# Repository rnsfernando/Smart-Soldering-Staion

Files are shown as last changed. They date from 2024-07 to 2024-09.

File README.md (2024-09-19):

# Smart-Soldering-Staion
The SmartSolder Station is a high-performance soldering solution with a soldering iron and hot air gun. 
#### Features:

-Advanced PID Temperature Control  
-Rapid Heating  
-Sleep Mode  
-Tip Change Mode  
-Energy Efficient  
-Reliable Soldering

 Explore our documentation, schematics, and source code to build your own state-of-the-art soldering station.

<table>
  <tr>
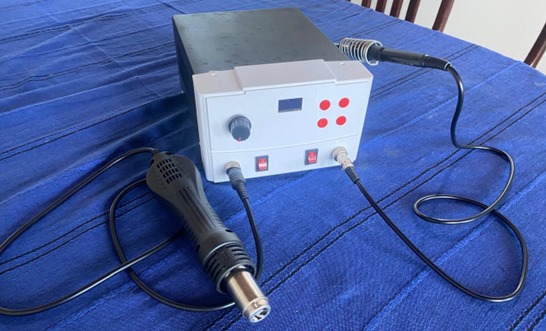
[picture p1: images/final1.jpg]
final1
    <td></td>
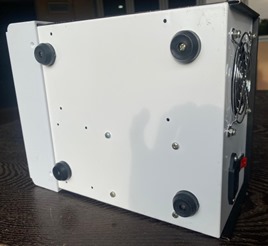
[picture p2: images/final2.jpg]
final2
    <td></td>
  </tr>
  <tr>
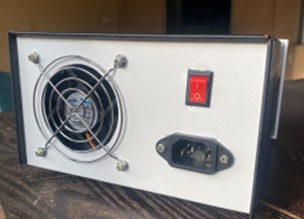
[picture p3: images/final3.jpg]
final3
    <td></td>
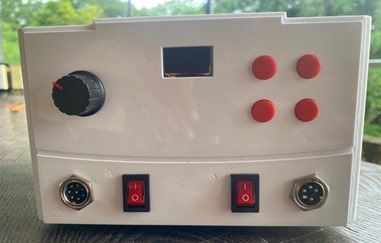
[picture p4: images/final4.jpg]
final4
    <td></td>
  </tr>
</table>

## Table of Contents
- [Introduction](#introduction)
- [Overview](#overview)
- [System Block Diagram](#system-block-diagram)
- [Schematic Diagram](#schematic-diagram)
- [PCB Layout](#pcb-layout)
- [Component List](#component-list)
- [Microcontroller Programming](#microcontroller-programming)
- [Operation](#operation)
- [Safety Features](#safety-features)

## Introduction
The ATmega328P Soldering Station is designed to provide precise temperature control for soldering tasks. This document outlines the design, components, and operation of the soldering station.

## Overview
This soldering station utilizes the ATmega328P microcontroller for temperature control, providing accurate and stable performance. The user interface includes an LCD display and push buttons for setting and monitoring the temperature.

## System Block Diagram
The system block diagram illustrates the main components and their interactions within the soldering station. The microcontroller reads the temperature sensor and controls the heating element to maintain the desired temperature. The user interface allows the user to set the temperature and view the current status.
Block-Diagram

## Schematic Diagram
The schematic diagram provides a detailed view of the electrical connections and components used in the soldering station.

## PCB Layout

### DC PCB
#### Top Layer
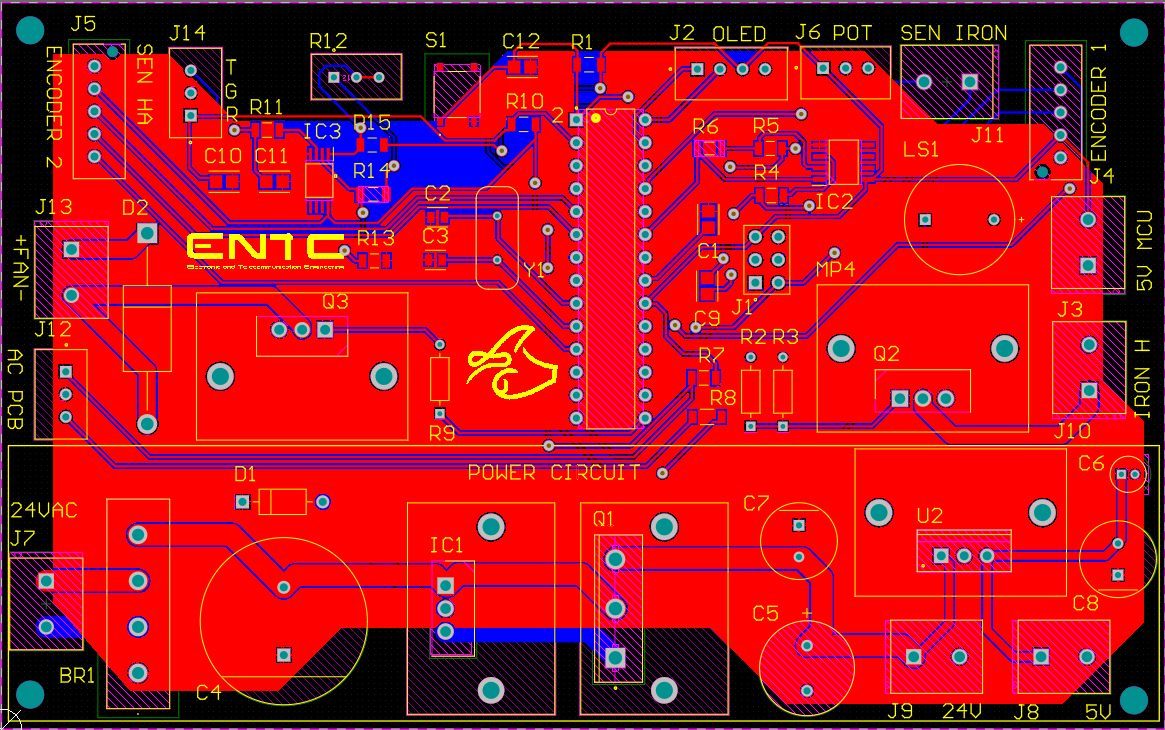
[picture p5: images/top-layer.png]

#### Bottom Layer
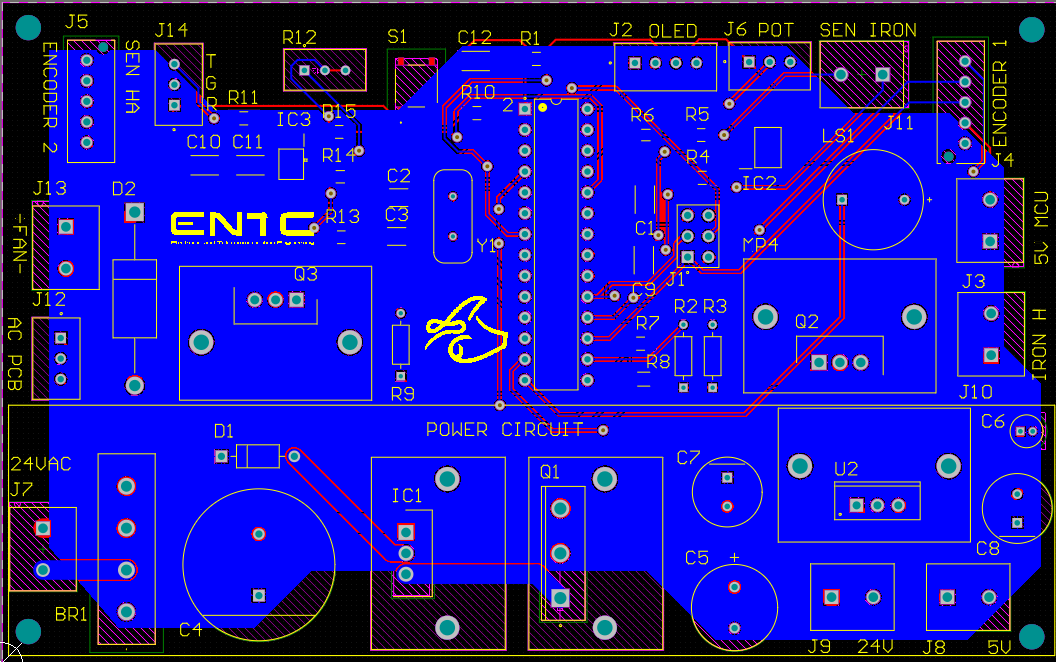
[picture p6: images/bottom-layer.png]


### AC PCB
#### Top Layer
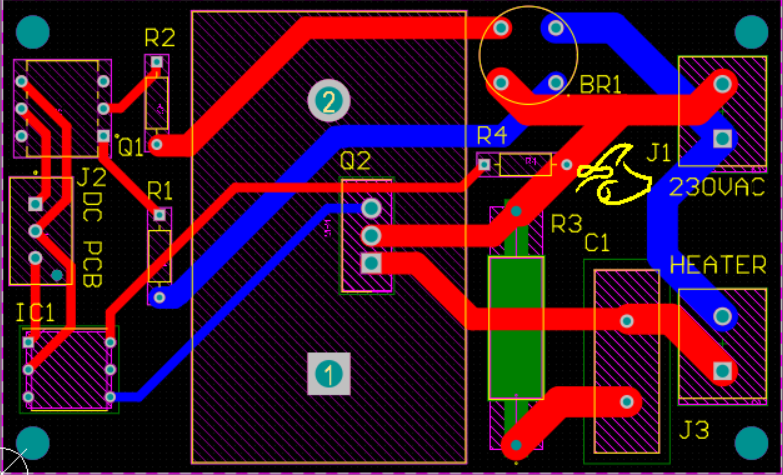
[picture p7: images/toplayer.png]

#### Bottom Layer
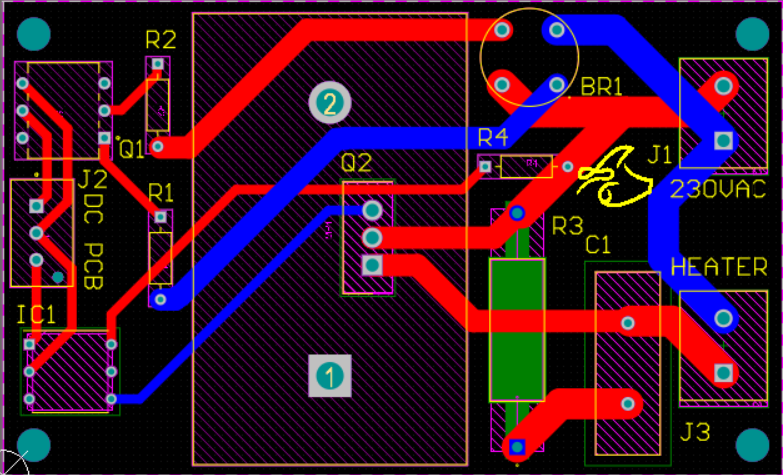
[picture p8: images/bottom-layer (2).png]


### 3D View
### DC PCB
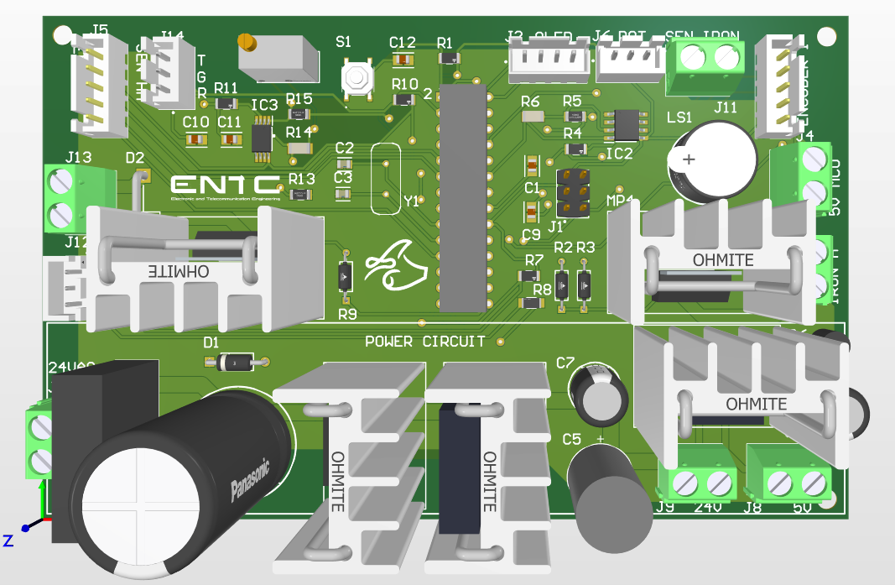
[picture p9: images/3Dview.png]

### AC PCB
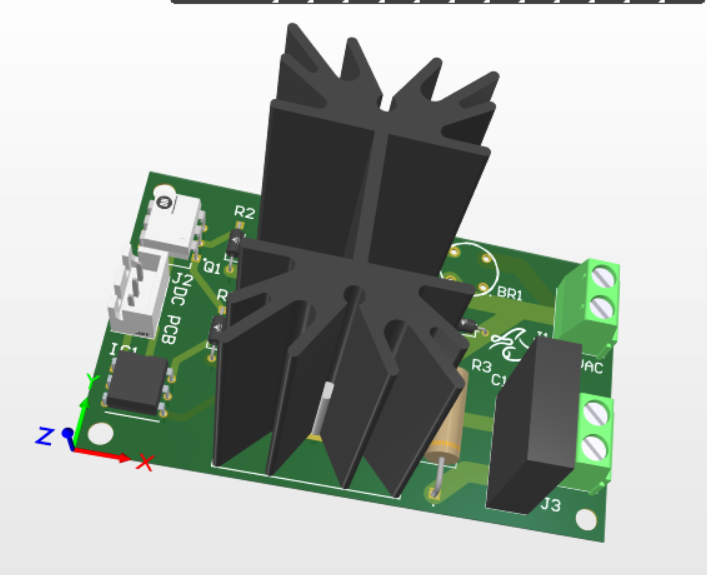
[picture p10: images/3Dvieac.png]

The PCB layout shows the placement of components on the board. The design optimizes space and ensures proper heat dissipation.

## Printed PCB

### DC PCB
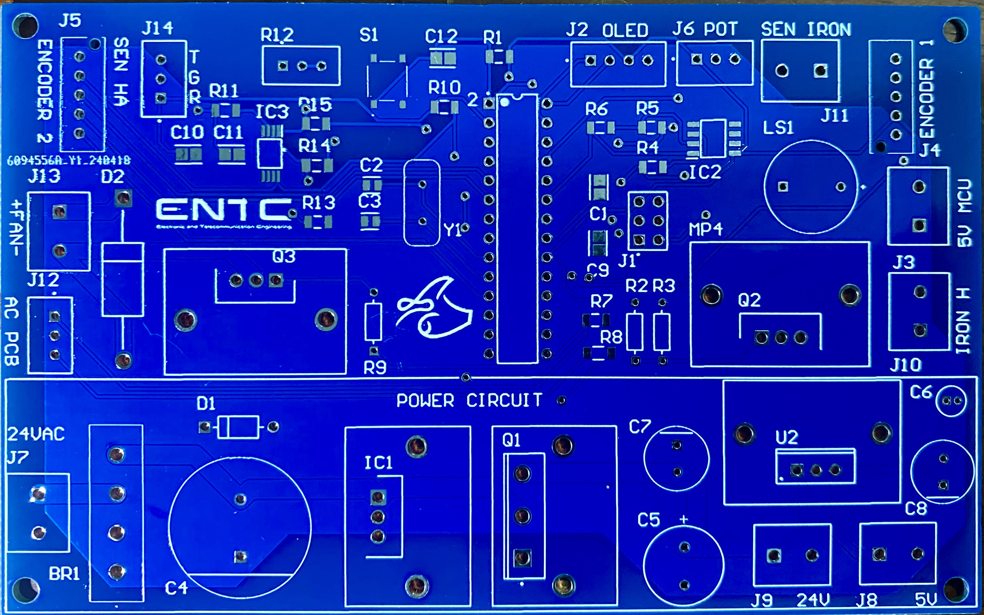
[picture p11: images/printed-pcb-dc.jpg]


### AC-PCB
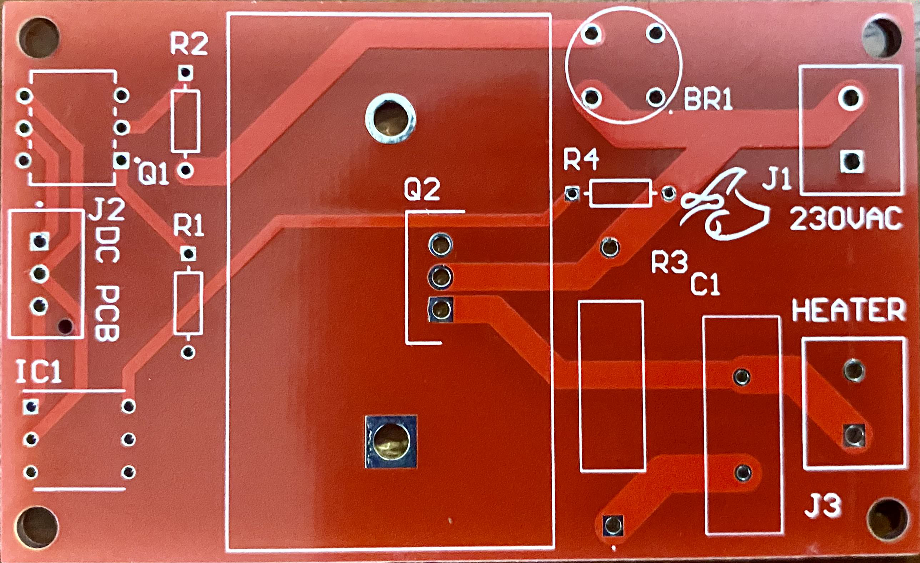
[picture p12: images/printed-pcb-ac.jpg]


## Component List
- **Microcontroller:** ATmega328P
- **Display:** 16x2 LCD screen
- **Temperature Sensor:** Thermocouple
- **Controls:** Push buttons
- **Heating Element:** Soldering iron
- **Other Components:** Resistors, capacitors, connectors

## Wiring Diagram
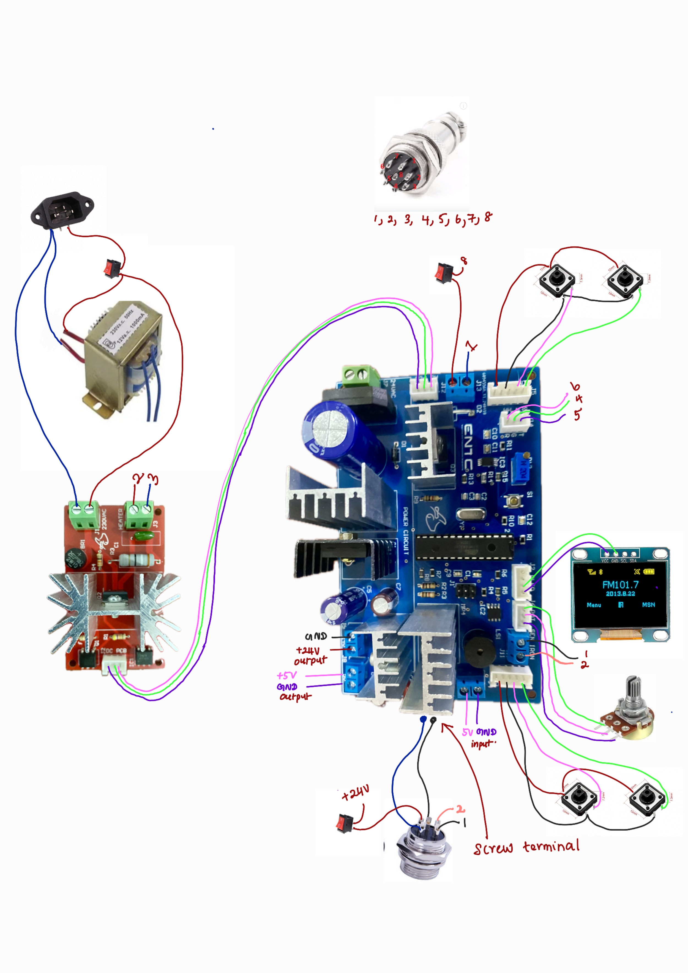
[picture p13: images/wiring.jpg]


## Microcontroller Programming
The ATmega328P microcontroller is programmed using Atmel Studio. Follow these steps to configure and upload the code:

1. **Install Atmel Studio:** Download and install Atmel Studio.
2. **Open Project:** Open the provided project file in Atmel Studio.
3. **Configure Settings:** Set the microcontroller (ATmega328P) and configure fuse bits.
4. **Write Code:** Develop or modify the code as needed.
5. **Build Project:** Compile the project to check for errors.
6. **Upload Code:** Use a programmer (e.g., USBasp) to upload the compiled code to the ATmega328P.

```c
// Example Code Snippet
#include <avr/io.h>
#include <util/delay.h>

#define F_CPU 16000000UL

int main(void) {
    // Set up code
    DDRB |= (1 << PB0); // Set PB0 as output

    while (1) {
        // Main loop
        PORTB ^= (1 << PB0); // Toggle PB0
        _delay_ms(1000); // Delay 1 second
    }
    return 0;
}
The SmartSolder Station is a high-performance soldering solution with a soldering iron and hot air gun. Featuring advanced PID temperature control and multiple modes, it ensures precise, efficient, and reliable soldering. Explore our documentation, schematics, and source code to build your own state-of-the-art soldering station.

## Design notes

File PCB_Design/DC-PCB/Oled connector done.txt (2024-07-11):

Oled connector  done
buzzer
current control done
sensoer input
cooling fan
led(not ness)

**** rotery encoder
pins to code 

24 v fan (24 nvolt ouyput
)
oled ekata 3.3 ekkakuth danna
two switched for iron and hot air gun

power circuit heat sink size care 

power circuit heat sink 

resistor voltage double cheak

5V 5V CONNECT VENATHAN 24 CONNECT VENA CONNECTORS EKA LAGA THYANNA

oni socket tika venama balanna

ho

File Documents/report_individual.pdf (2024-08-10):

## Digital Soldering station

W.W.R.N.S. Fernando – 210169L

## Contribution Report

In this project, I played a significant role in several key areas, ensuring the successful completion of our advanced soldering station. My contributions can be categorized into the following domains:

### 1. SolidWorks Design

I was mainly responsible for the SolidWorks design of the soldering station. This involved:

- 3D Modeling: Creating detailed 3D models of the soldering station components, ensuring precise dimensions and functional design.
- Design Iterations: Collaborating with the team to iterate on the design based on feedback, ensuring the final product met all technical and user requirements.

### 2. Software Development

I also took the lead in the software development aspect of the project, focusing on:

- Temperature Control Algorithm: Developing a robust PID control algorithm to regulate the soldering iron's temperature with high precision.
- Microcontroller Programming: Writing and debugging the code for the microcontroller that manages the soldering station's functions, including temperature control, sleep mode, and tip change mode.
- User Interface: Designing a user-friendly interface that displays real-time temperature readings and allows users to adjust settings easily.

### 3. Design Methodology

Throughout the project, I actively contributed to the overall design methodology, including:

- Concept Development: Participating in brainstorming sessions to develop innovative concepts and features for the soldering station.
- Decision Making: Assisting in the decision-making process by evaluating different design options and selecting the most feasible solutions.
- Prototyping: Helping to build and test prototypes to validate design concepts and refine the final product.

### 4. Circuit Design Finalization

In addition to my primary focus areas, I contributed to finalizing the circuit designs by:
- Circuit Design Review: Reviewing circuit schematics to ensure they met the project's requirements and industry standards.
- Component Selection: Assisting in selecting appropriate components that provided reliable performance and compatibility with the overall design.
- Testing and Validation: Helping to test and validate the circuits to ensure they functioned correctly and integrated well with the rest of the system.

### 5. Documentation Assistance

Lastly, I supported the documentation process by:

- Design Documentation: Assisting in creating detailed technical documents that described the solid works design, and software part of the soldering station.
- Design methodology: Contributed to developing the design methodology report based on the Cambridge model.

### 6. PCB design

I contributed to finalizing the PCB design by:

- PCB Layout: Assisting in the design of the PCB layout to ensure optimal component placement, signal integrity, and manufacturability.
- Design Review: Reviewing the PCB design to ensure it met all project requirements and industry standards.
- Component Selection: Helping to choose suitable components that provided reliable performance and compatibility with the overall design.
- Testing and Validation: Participating in the testing and validation process to ensure the PCB functioned correctly and integrated seamlessly with the rest of the system.

### 7. PCB Soldering and Testing

I contributed to soldering and testing the PCB:

- PCB Soldering: Assisted in soldering the PCBs to ensure all components were properly attached.
- MCU Circuit Testing: Participated in testing the Microcontroller Unit (MCU) circuit to verify its functionality.
- Power Supply Circuit Testing: Conducted tests on the power supply circuit to ensure it operated correctly.
- Functionality Confirmation: Verified that both circuits worked as intended and that the soldering was done accurately.

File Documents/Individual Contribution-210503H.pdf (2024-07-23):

# Department of Electronics and Telecommunications

## University of Moratuwa

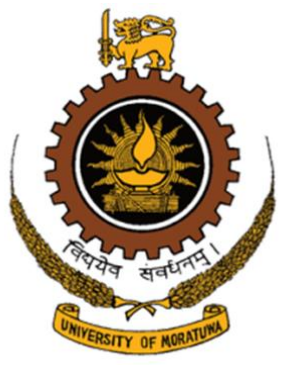
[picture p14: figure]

# Individual Contribution Report: Soldering Station Project

EN2160

## Engineering Design Realization

## 210503H- I.P.D.D. Rajapaksha

This report highlights my individual contributions to the soldering station project. My involvement spanned various phases, including research, design, simulation, prototyping, component selection, schematic and PCB design, code finalization, and testing. The following sections detail each contribution.

Research and Circuit Design

I conducted extensive research in two main categories: product analysis and circuit design. First, I focused on industrial products and market-available products, examining their features and specifications to understand the current standards and innovations. This research provided valuable insights into what makes a successful soldering station. Secondly, I delved into circuit design, specifically for both AC and DC circuits. I explored various sub-circuits, learning about their functions and how to integrate them effectively. This foundational work on product features and circuit design was crucial in ensuring the project's success and informed the overall development of both the AC and DC PCB circuits.

Circuit Design

I was responsible for designing the circuits for two separate PCBs: the AC PCB and the DC PCB. This involved creating detailed schematics and layout designs, including essential circuits such as the current-controlling power supply, MCU, temperature sensing and amplifying, and the AC PCB with TRIAC trigger configuration. I used industry-standard design software to optimize these designs for performance and reliability. These designs were crucial for the efficient and reliable operation of the soldering station.

Schematic and PCB Design for AC and DC Circuits

I created detailed schematics and PCB layouts for both the AC and DC circuits. This work required precision and attention to detail to ensure that the circuits would function correctly and safely. The designs were thoroughly reviewed and optimized for manufacturing.

Simulation and Prototyping

To validate the circuit designs, I performed simulations using Multisim. These simulations helped identify potential issues and allowed for iterative improvements. Following successful simulations, I constructed a prototype using a dotboard to test the power supply circuit. This hands-on testing confirmed the circuit's functionality and performance under real-world conditions, ensuring its stability and reliability.

Component Selection

Another significant contribution was selecting the appropriate components for the project. This task required careful consideration of various factors such as compatibility, reliability, and cost. I performed the relevant calculations to ensure optimal performance and selected high-quality components that would guarantee the soldering station's reliable and efficient operation.

Enclosure Design

I assisted in finalizing the design of the enclosure for the soldering station. This involved collaborating with the team to ensure the enclosure was both functional and aesthetically pleasing. The enclosure design needed to accommodate all components securely while allowing for adequate ventilation and ease of use.

Software Development

Another significant contribution was the software development for the project. I conducted thorough research to identify relevant techniques and features needed for the soldering station. Based on this research, I finalized the structure of the algorithm, ensuring it incorporated essential features such as PID control, pin change mode, sleep mode, and others. I played a crucial role in finalizing the main code, debugging, and refining it to ensure seamless integration with the hardware. This structured approach to coding was essential for the efficient and reliable operation of the soldering station, managing temperature control and other functionalities effectively.

Soldering and Testing

I participated in soldering the PCBs and testing the MCU (Microcontroller Unit) circuit and power supply circuit. These tests confirmed that the circuits worked as intended and that the soldering was done correctly. The successful testing phase was a critical step in moving the project toward completion.

Documentation Assistance

Technical Documentation: Assisting in the creation of comprehensive technical documents that detailed the circuit design, including schematics and PCB layout for various parts of the soldering station.

Design Methodology: Contributing to the development of the design methodology report, which was based on the Cambridge model, ensuring a structured and methodical approach to the design process.

This comprehensive research encompassed product analysis and circuit design, providing essential insights into industry standards and innovative practices. It was instrumental in shaping the development of both AC and DC PCB circuits for the soldering station, ensuring their effective integration and optimal performance.

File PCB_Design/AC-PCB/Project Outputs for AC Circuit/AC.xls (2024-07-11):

Board Stack Report
Stack Up |  | Layer Stack
Layer | Board Layer Stack | Name | Material | Thickness | Constant
1 |  | Top Overlay |  | 0mil
2 |  | Top Solder | Solder Resist | 0.4mil | 3.5
3 |  | Top Layer |  | 1.4mil
4 |  | Dielectric 1 | FR-4 | 12.6mil | 4.8
5 |  | Bottom Layer |  | 1.4mil
6 |  | Bottom Solder | Solder Resist | 0.4mil | 3.5
7 |  | Bottom Overlay |  | 0mil
 | Height : 16.2mil

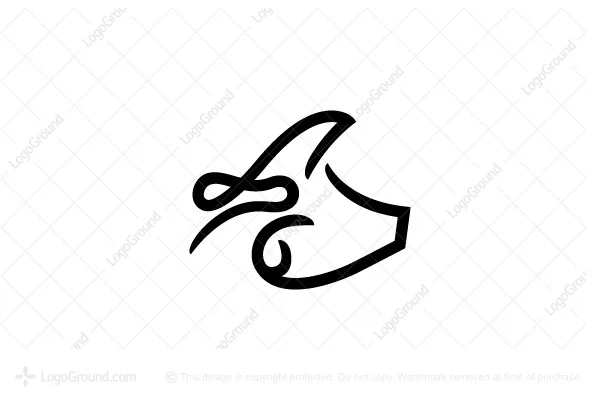
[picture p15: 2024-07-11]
PCB_Design/DC-PCB/dv12y202344582023-11-183462807chicken and pig head farm-01.png

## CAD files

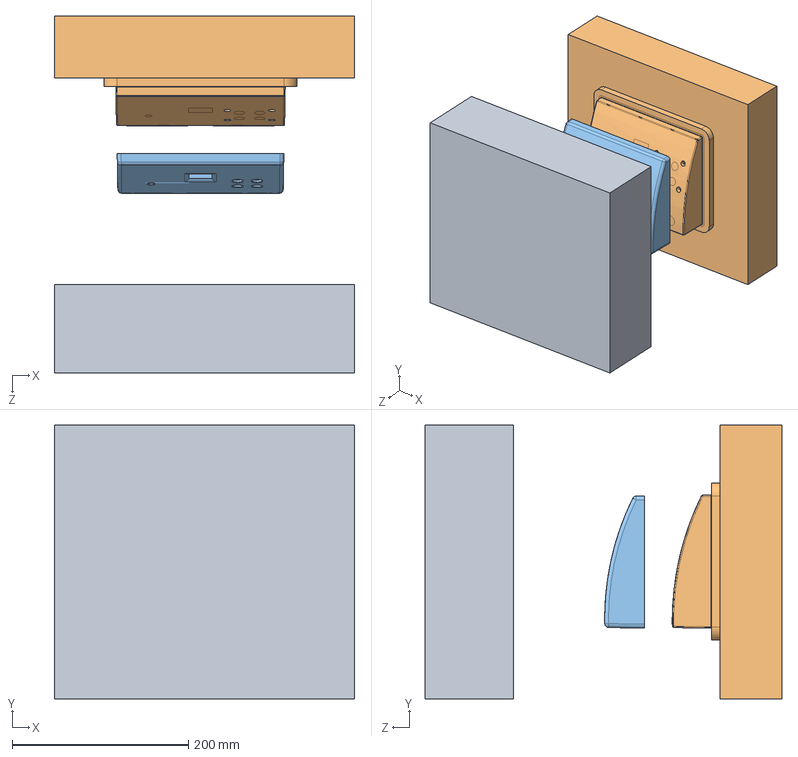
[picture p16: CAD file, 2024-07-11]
Enclosure-Design/Mold-Design/1.0-Design/Assem1.SLDASM
340.0 x 310.0 x 404.4 mm
face-cavity
face-core
new_face

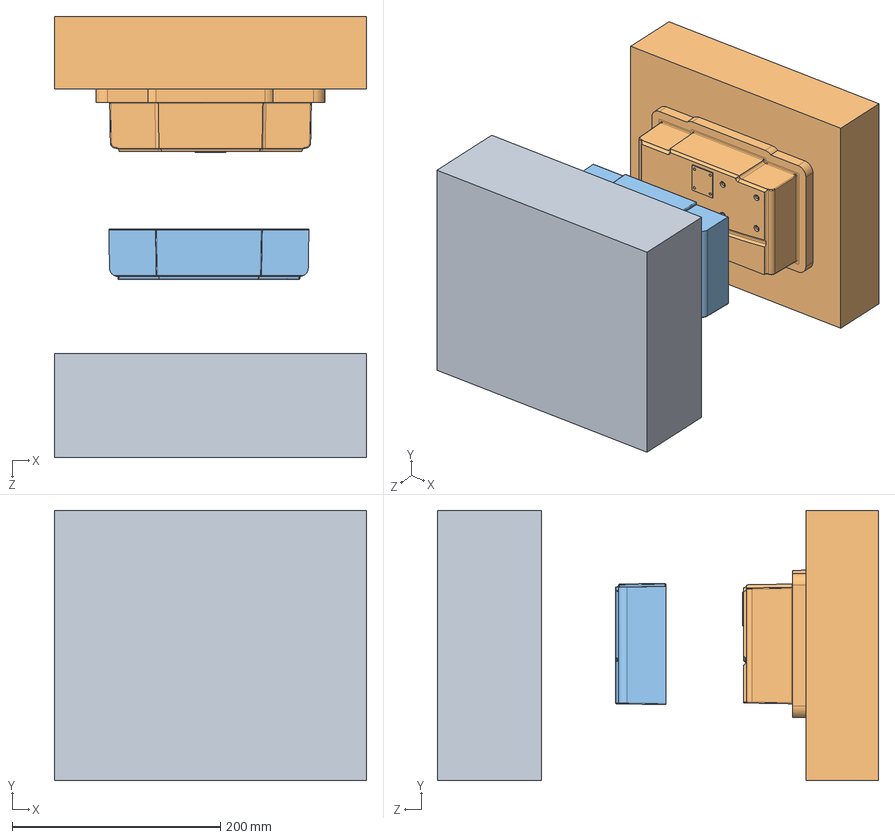
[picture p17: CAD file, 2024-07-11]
Enclosure-Design/Mold-Design/2.0-Design/Assem2.SLDASM
300.0 x 260.0 x 424.3 mm
metal final face_moldable-Cavity
metal final face_moldable-Core
final face_moldable

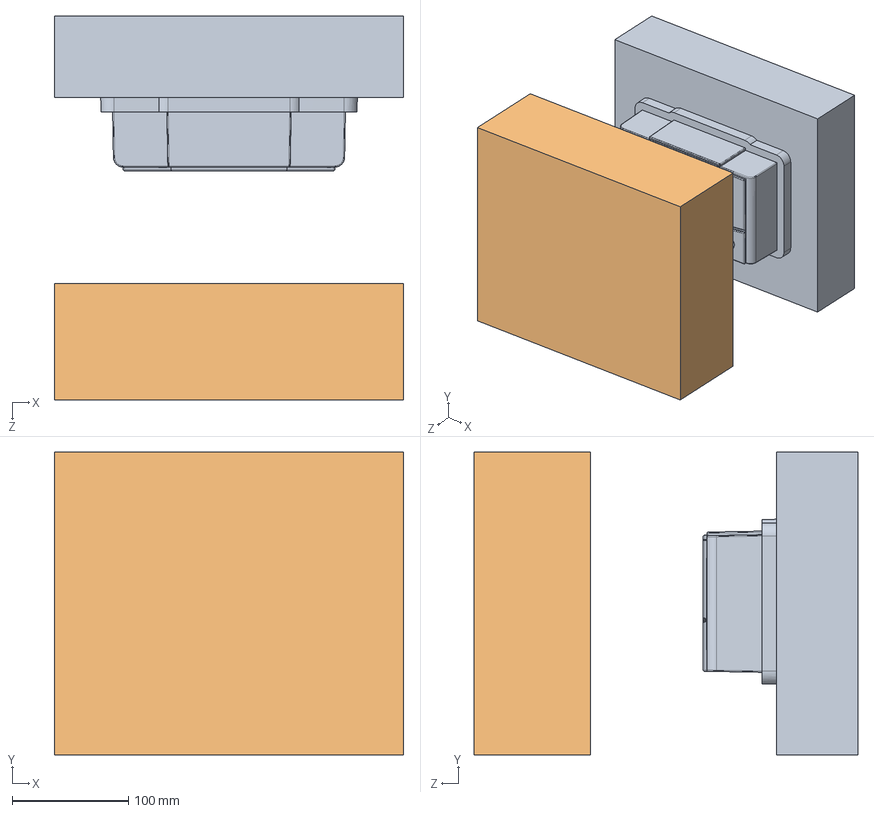
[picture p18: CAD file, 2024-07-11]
Enclosure-Design/Mold-Design/2.0-Design/Assem1.SLDASM
300.0 x 260.0 x 330.0 mm
metal final face_moldable
metal final face_moldable-Cavity

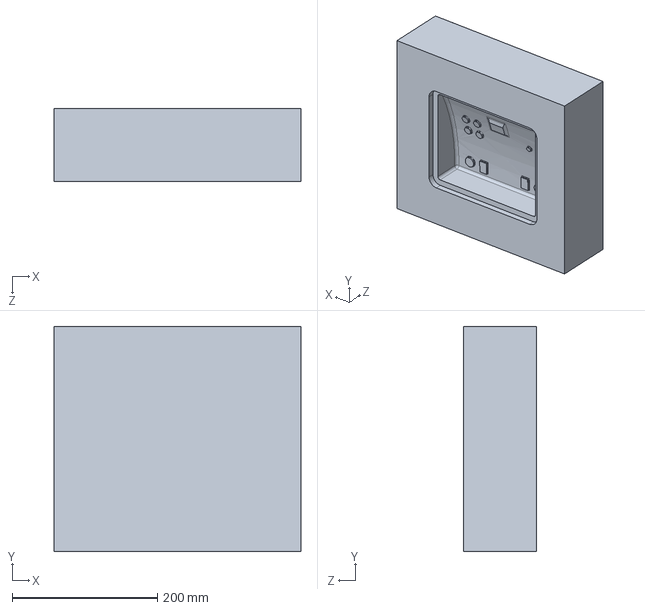
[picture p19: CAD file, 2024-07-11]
Enclosure-Design/Mold-Design/1.0-Design/face-cavity.SLDPRT
340.0 x 310.0 x 100.0 mm

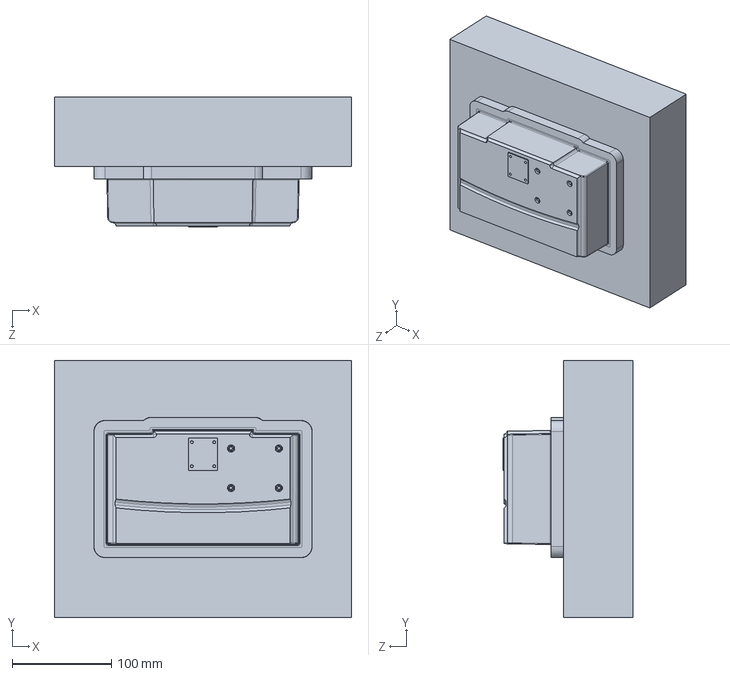
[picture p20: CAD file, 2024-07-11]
Enclosure-Design/Mold-Design/2.0-Design/metal final face_moldable-Core.SLDPRT
300.0 x 260.0 x 131.1 mm

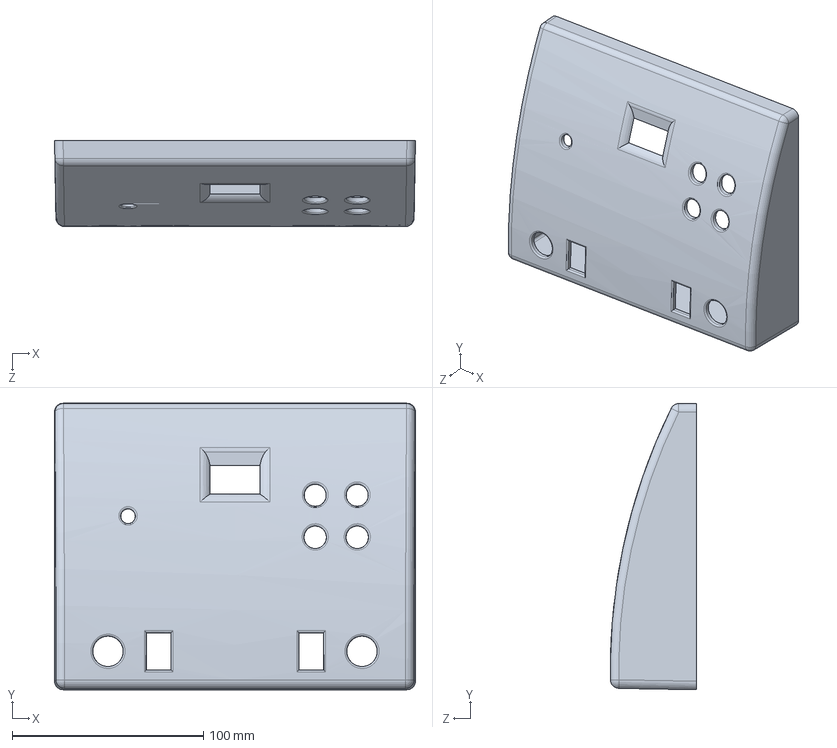
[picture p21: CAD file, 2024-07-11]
Enclosure-Design/Mold-Design/1.0-Design/Design1.SLDPRT
189.0 x 150.0 x 45.2 mm

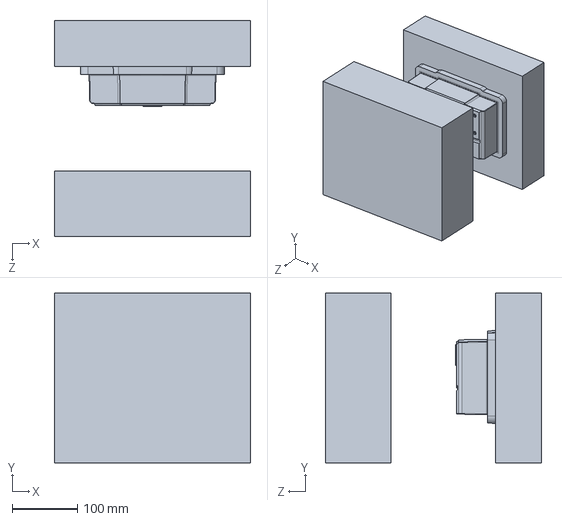
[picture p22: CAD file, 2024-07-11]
Enclosure-Design/Mold-Design/2.0-Design/metal final face_moldableboth.SLDPRT
300.0 x 260.0 x 330.0 mm

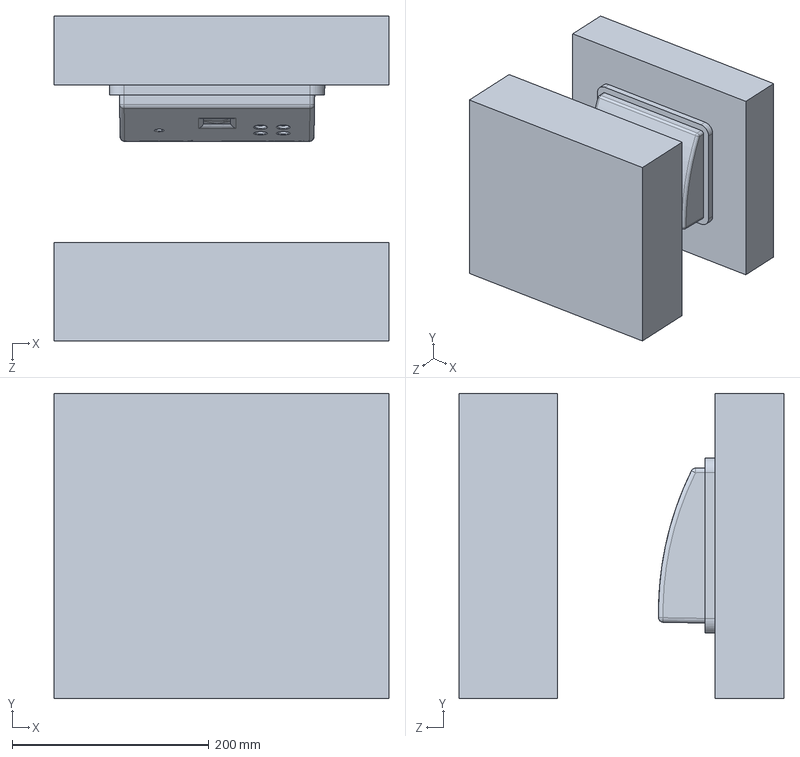
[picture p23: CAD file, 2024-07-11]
Enclosure-Design/Mold-Design/1.0-Design/face.SLDPRT
340.0 x 310.0 x 330.0 mm

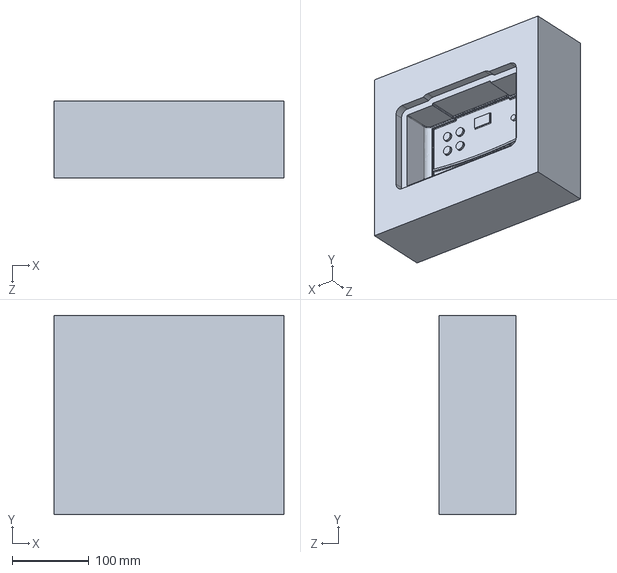
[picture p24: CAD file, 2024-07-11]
Enclosure-Design/Mold-Design/2.0-Design/metal final face_moldable-Cavity.SLDPRT
300.0 x 260.0 x 100.0 mm

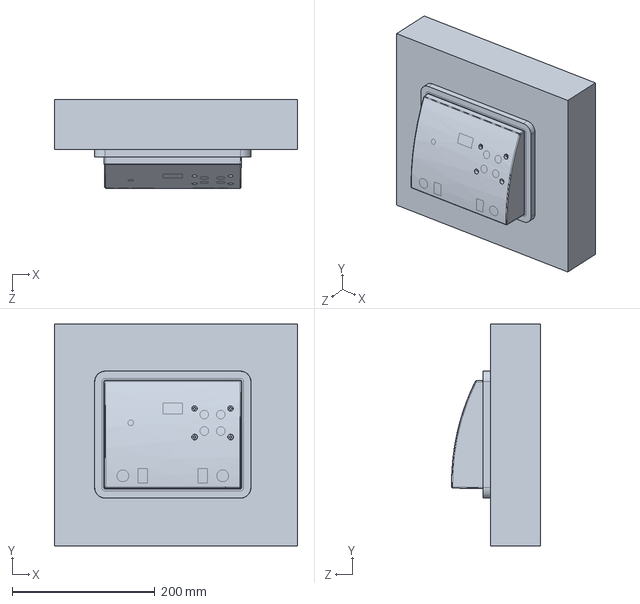
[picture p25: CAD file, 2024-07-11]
Enclosure-Design/Mold-Design/1.0-Design/face-core.SLDPRT
340.0 x 310.0 x 124.3 mm

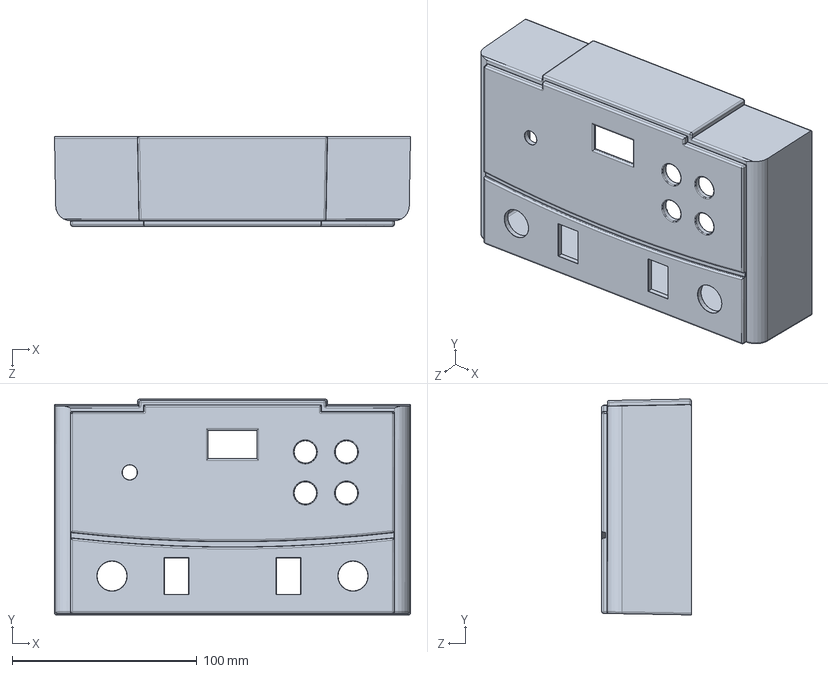
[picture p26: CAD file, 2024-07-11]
Enclosure-Design/Mold-Design/2.0-Design/final face_moldable.SLDPRT
192.5 x 116.7 x 48.5 mm

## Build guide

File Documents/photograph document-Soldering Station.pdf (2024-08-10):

# Department of Electronics and Telecommunications

# University of Moratuwa

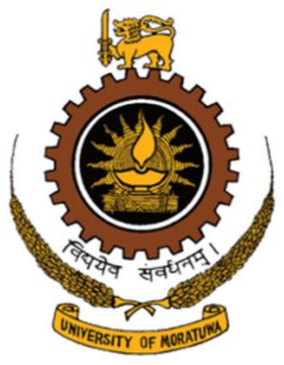
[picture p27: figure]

# Photographs Documentation

# Soldering Station

EN2160

## Engineering Design Realization

210169L- W.W.R.N.S. Fernando

210503H- I.P.D.D. Rajapaksha

## Contents

## 1.0. Photographs of the bare PCB

### 1.1. DC PCB

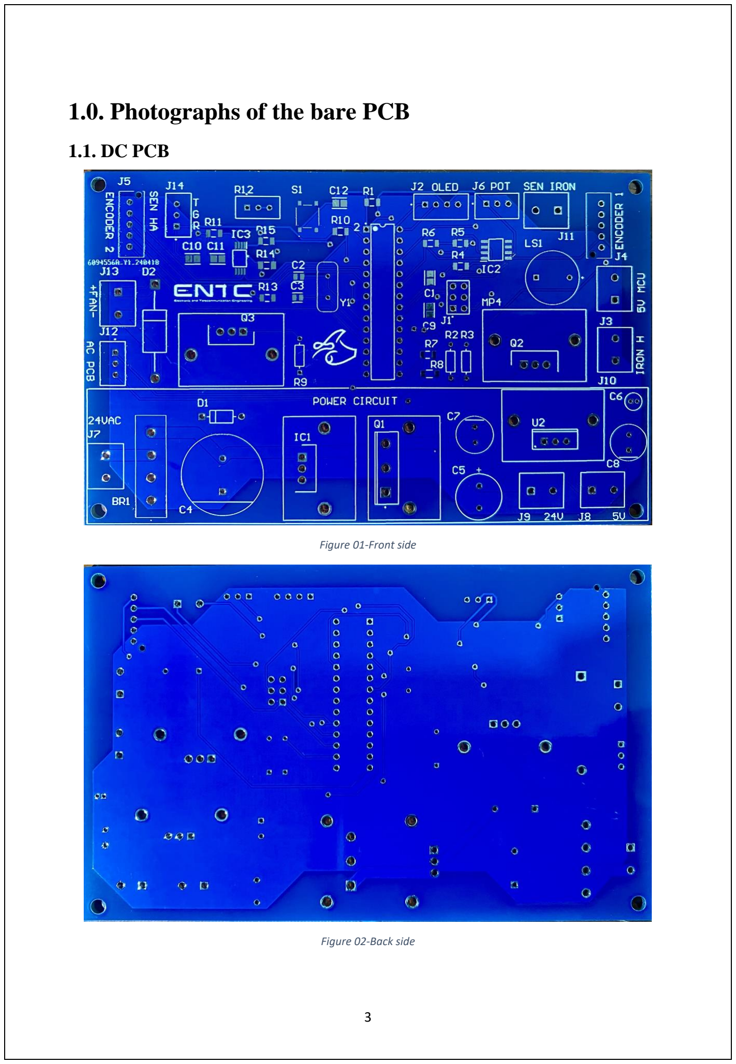
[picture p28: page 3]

Figure 01-Front side

Figure 02-Back side

### 1.2. AC PCB

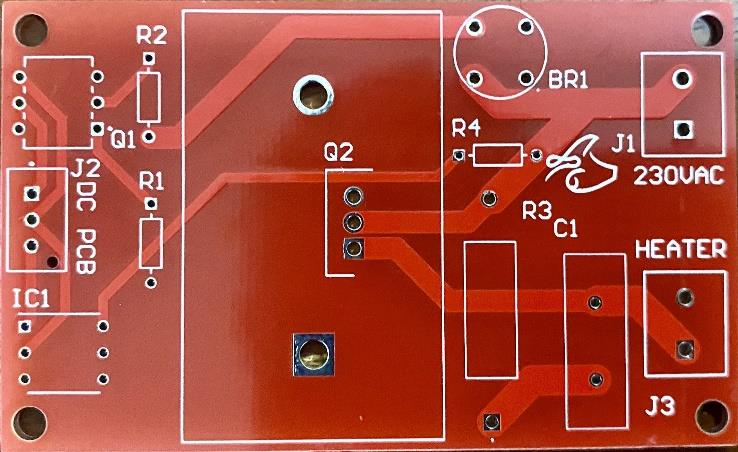
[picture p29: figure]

Figure 03-Front side

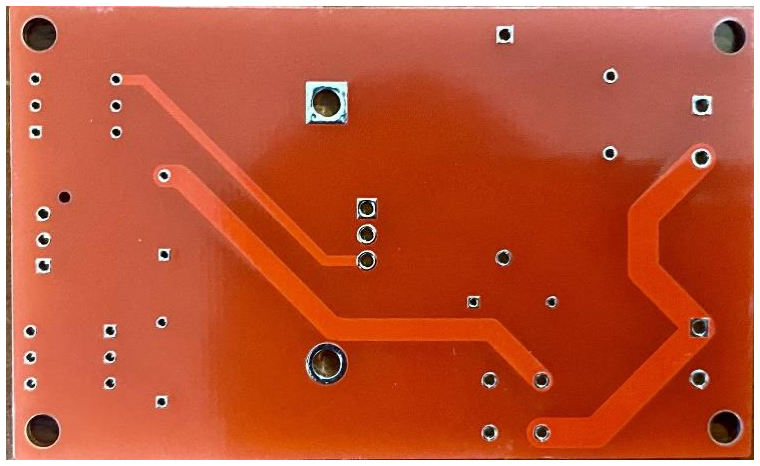
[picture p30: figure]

Figure 04-Back side

## 2.0. Photograph

### 2.1. DC PCB

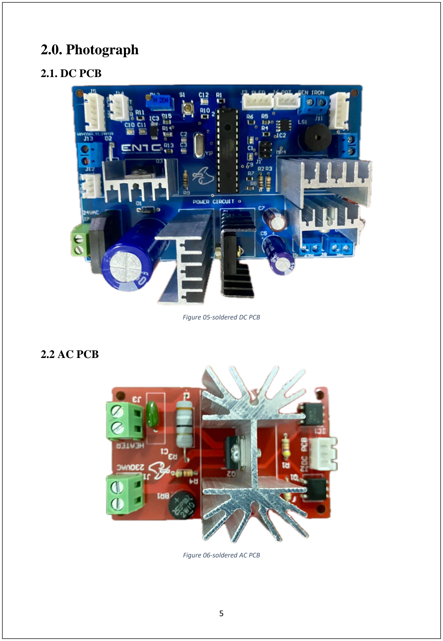
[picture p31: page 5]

Figure 05-soldered DC PCB

### 2.2 AC PCB

Figure 06-soldered AC PCB

## 3.0. Photographs as evidence for the PCB testing

The power supply circuit, microcontroller circuit, current controlling circuit, and amplifier circuit were tested before the labs closed due to a non-academic staff strike. The AC PCB, hot air current control, and amplifier still need to be tested, and the PID code for the soldering iron needs tuning. These tasks require a signal generator, an oscilloscope, and a power supply.

### 3.1. Sensor (Amplifier) testing

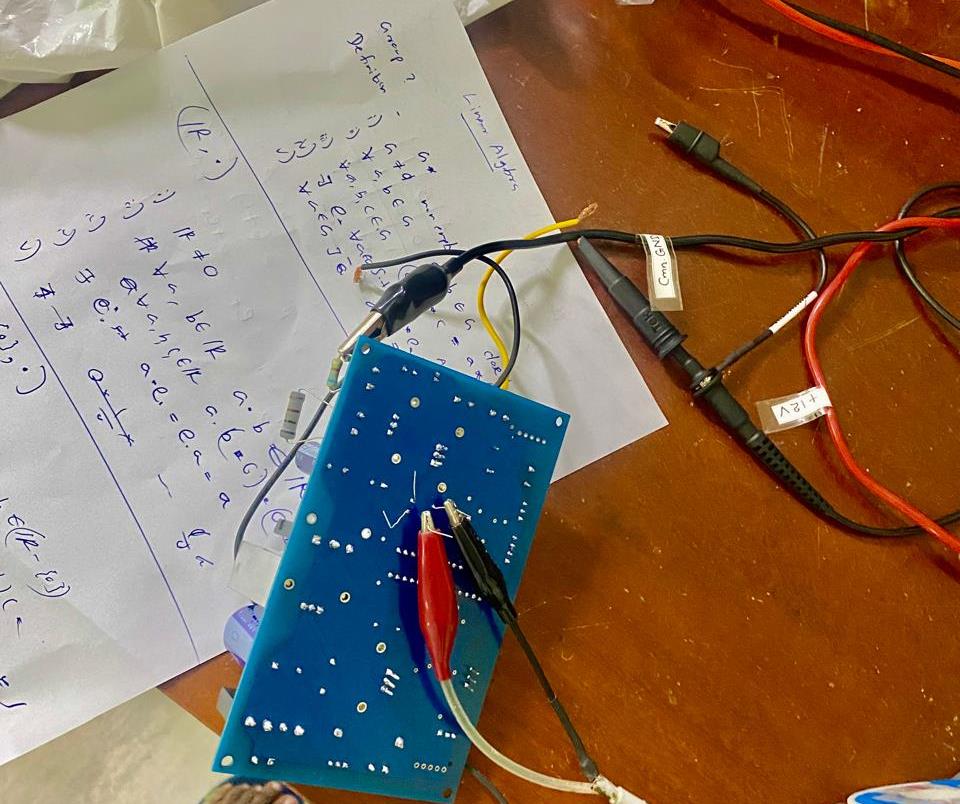
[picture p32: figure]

Figure 07 - Testing

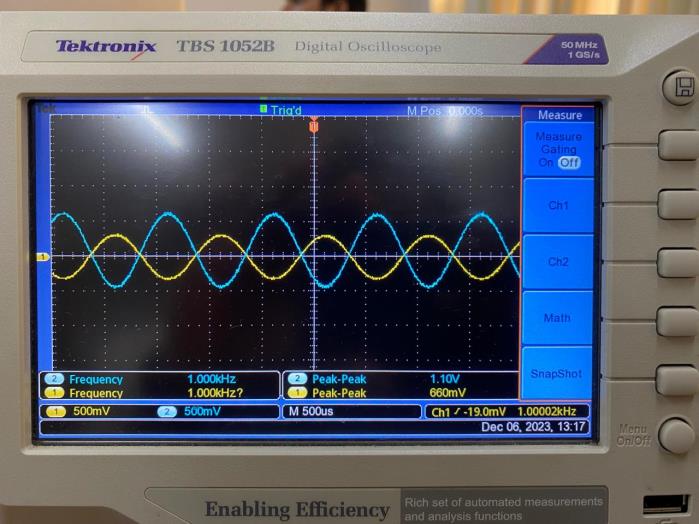
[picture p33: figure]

Figure 08 - Sensor output

## 4.0. Photographs of the physically built enclosure/functional (mechanical) parts

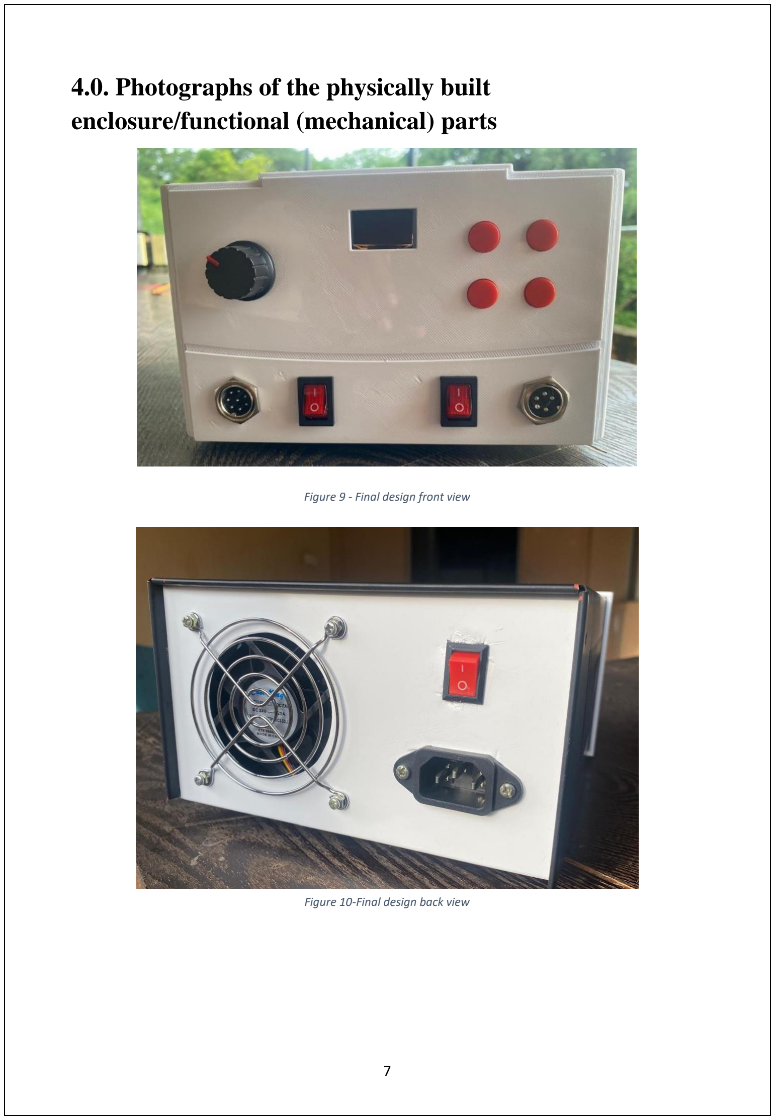
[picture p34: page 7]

Figure 9 - Final design front view

Figure 10-Final design back view

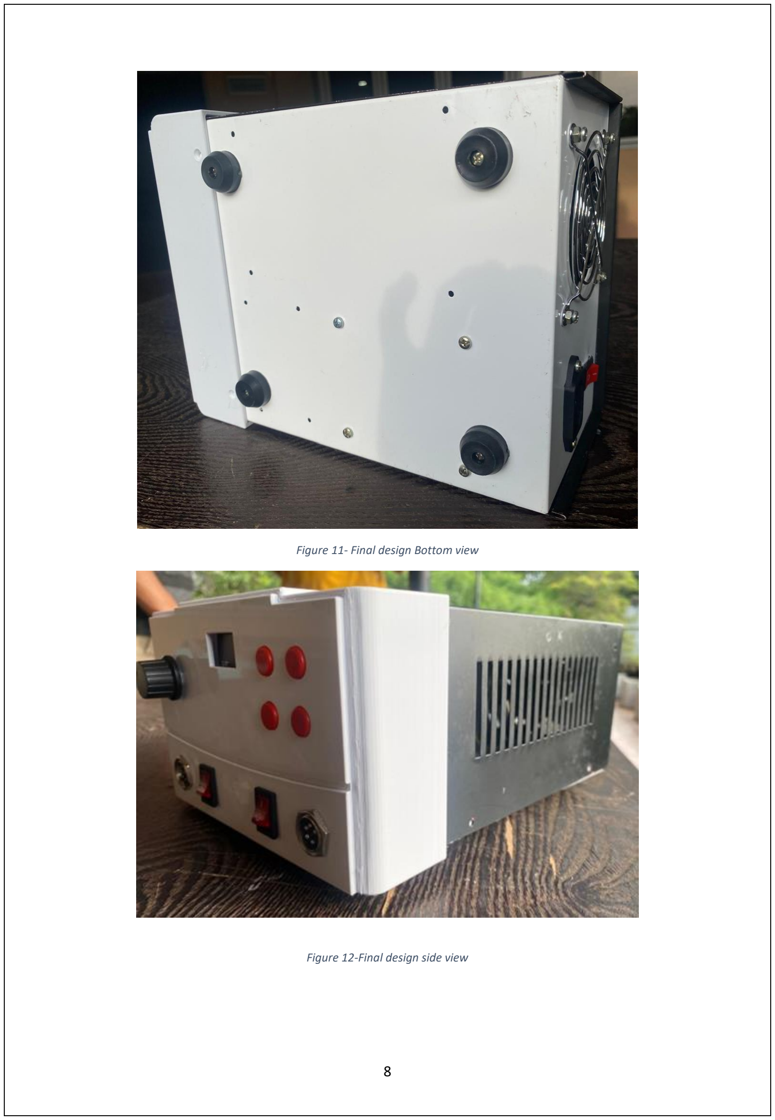
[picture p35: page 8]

Figure 11- Final design Bottom view

Figure 12-Final design side view

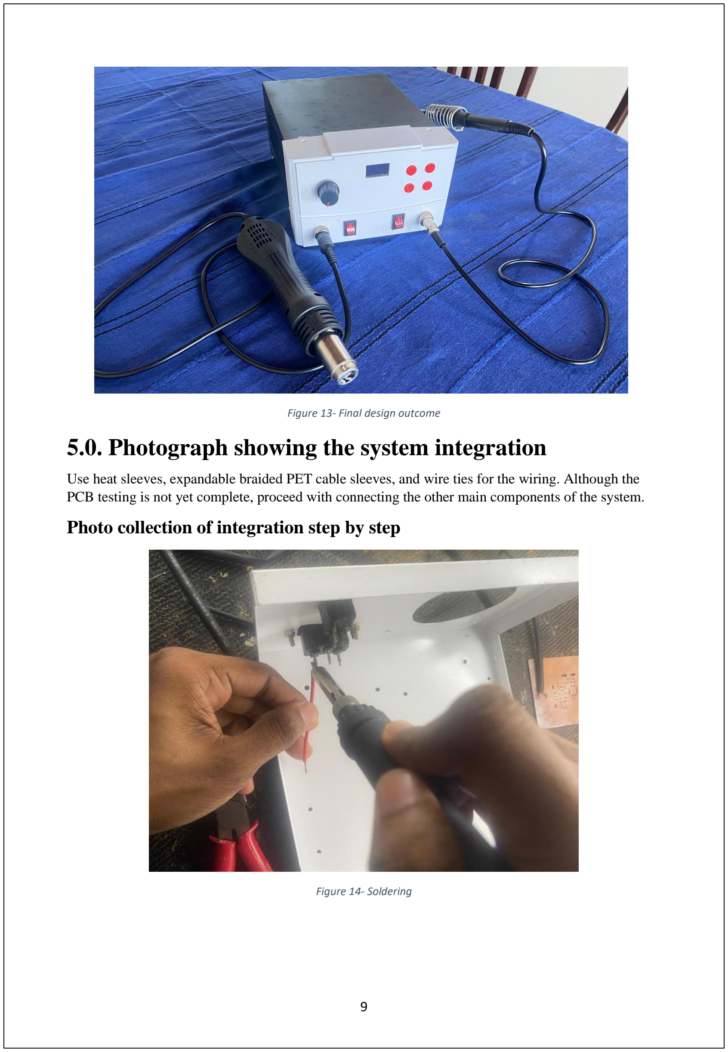
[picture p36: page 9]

Figure 13- Final design outcome

## 5.0. Photograph showing the system integration

Use heat sleeves, expandable braided PET cable sleeves, and wire ties for the wiring. Although the PCB testing is not yet complete, proceed with connecting the other main components of the system.

### Photo collection of integration step by step

Figure 14- Soldering

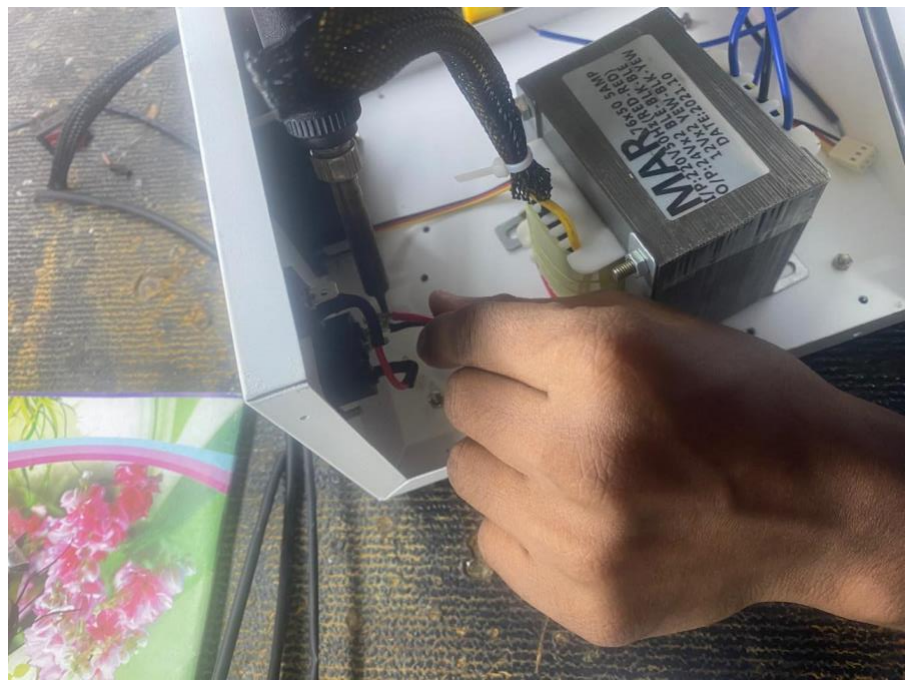
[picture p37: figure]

Figure 15-connecting transformer

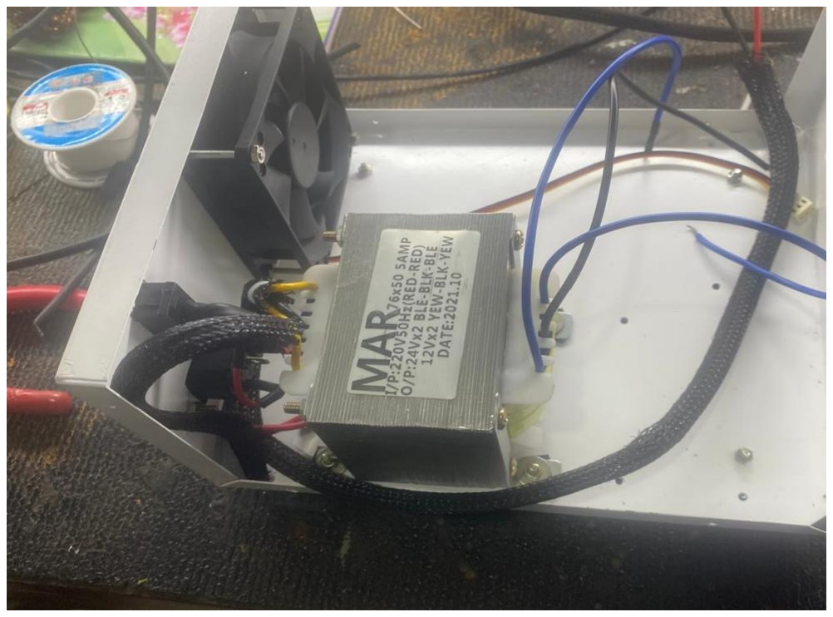
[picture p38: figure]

Figure 16- connected transformer

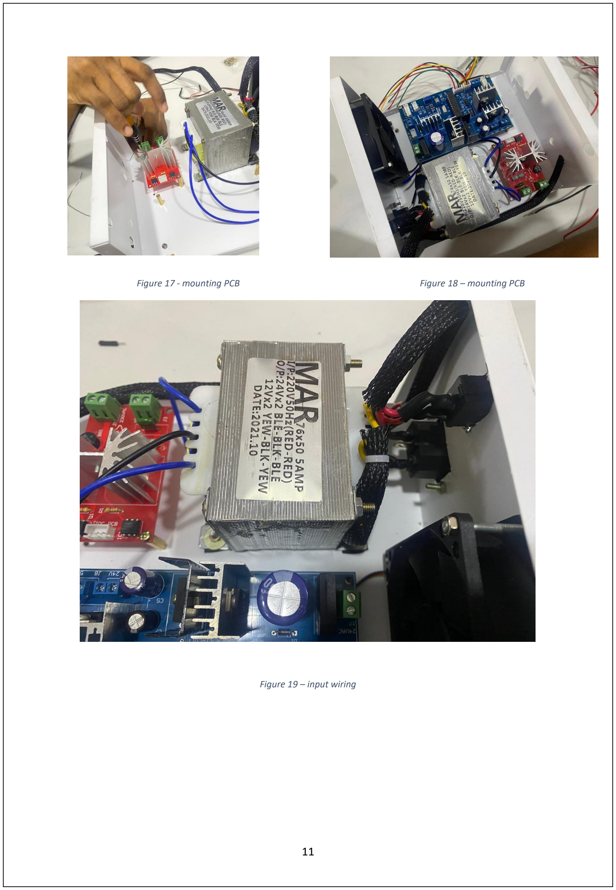
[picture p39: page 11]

Figure 17 - mounting PCB | Figure 18 – mounting PCB

Figure 19 – input wiring

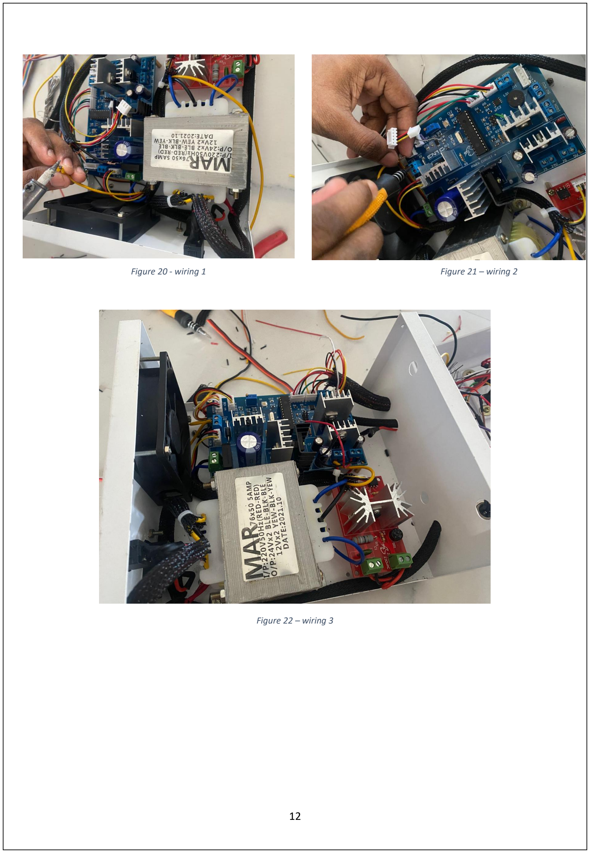
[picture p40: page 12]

Figure 20 - wiring 1 | Figure 21 – wiring 2

Figure 22 – wiring 3

# Outcome

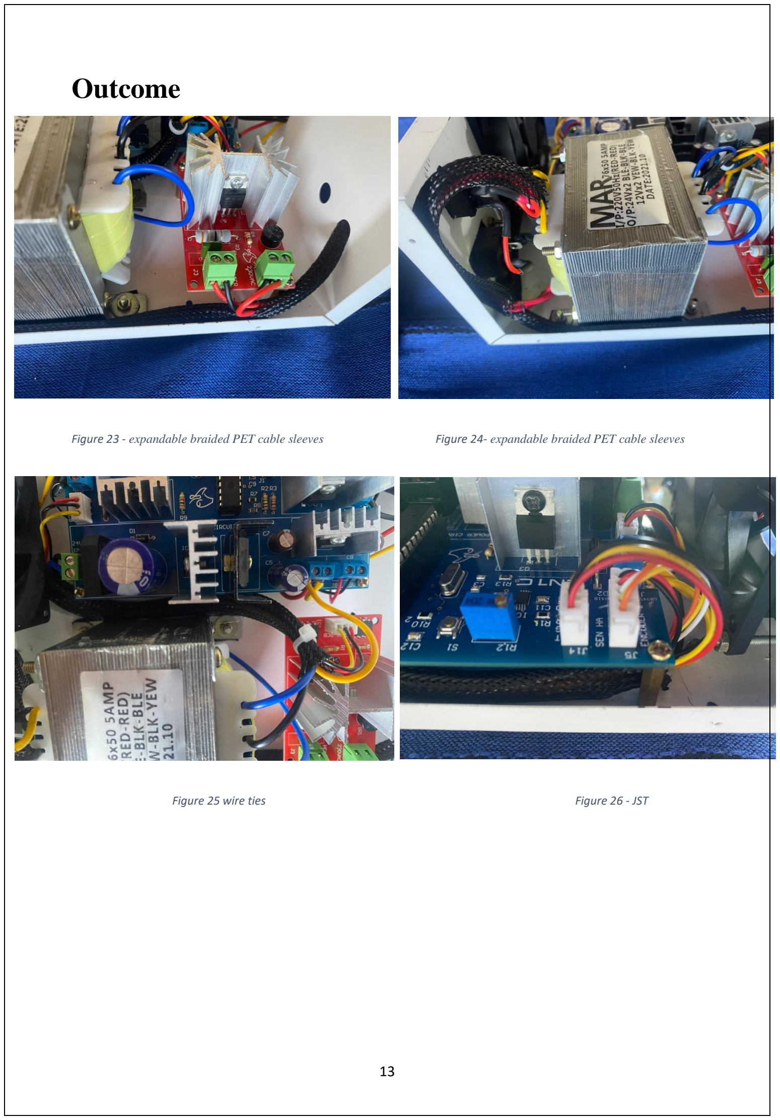
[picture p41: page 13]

Figure 23 - expandable braided PET cable sleeves | Figure 24- expandable braided PET cable sleeves
Figure 25 wire ties | Figure 26 - JST

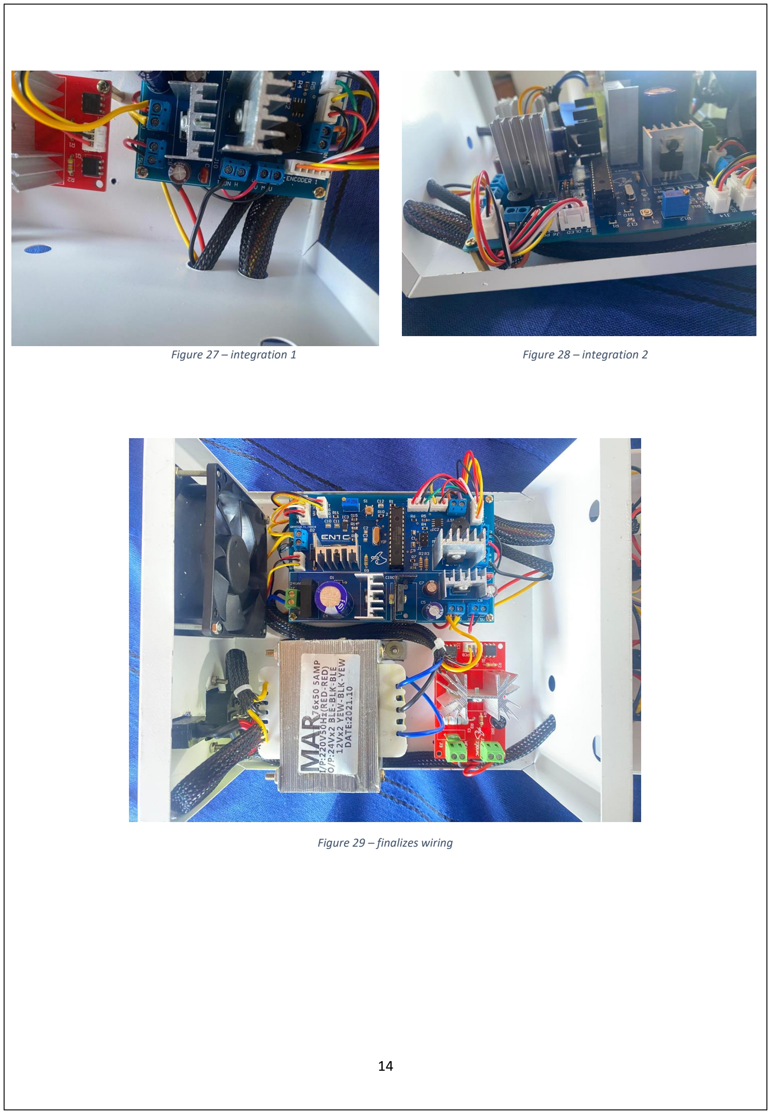
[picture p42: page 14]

Figure 27 – integration 1 | Figure 28 – integration 2

Figure 29 – finalizes wiring

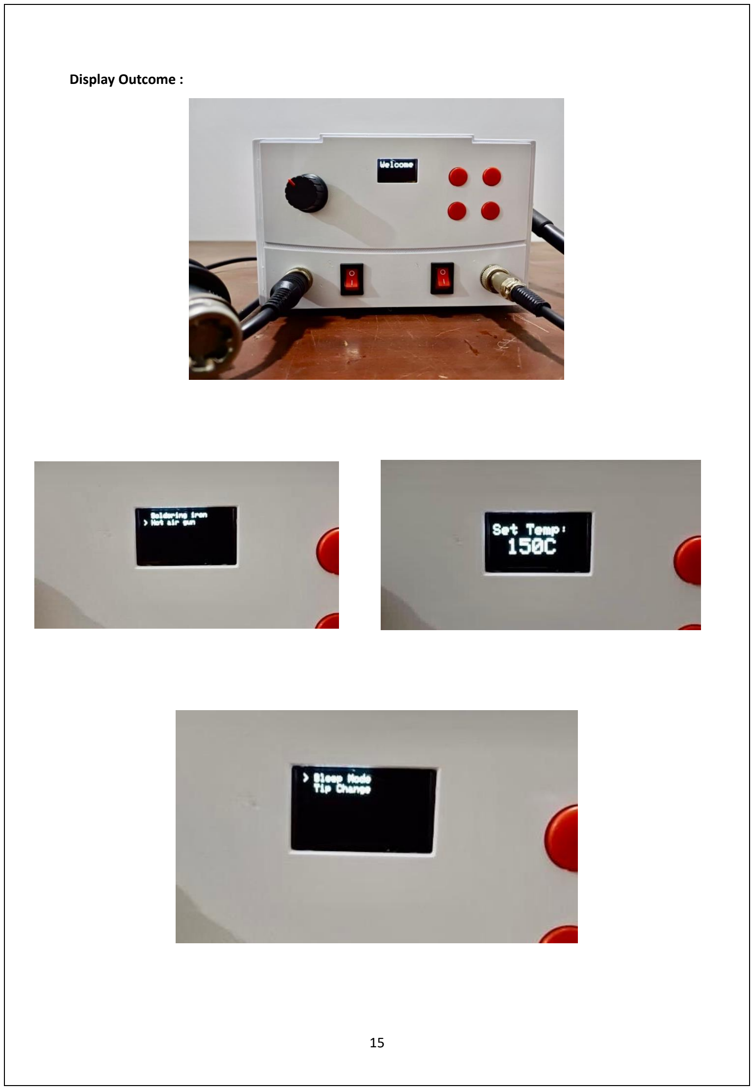
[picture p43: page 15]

Display Outcome :

## 6.0. Additional Photographs and sketches

### 6.1. Rough Sketches to Final Design

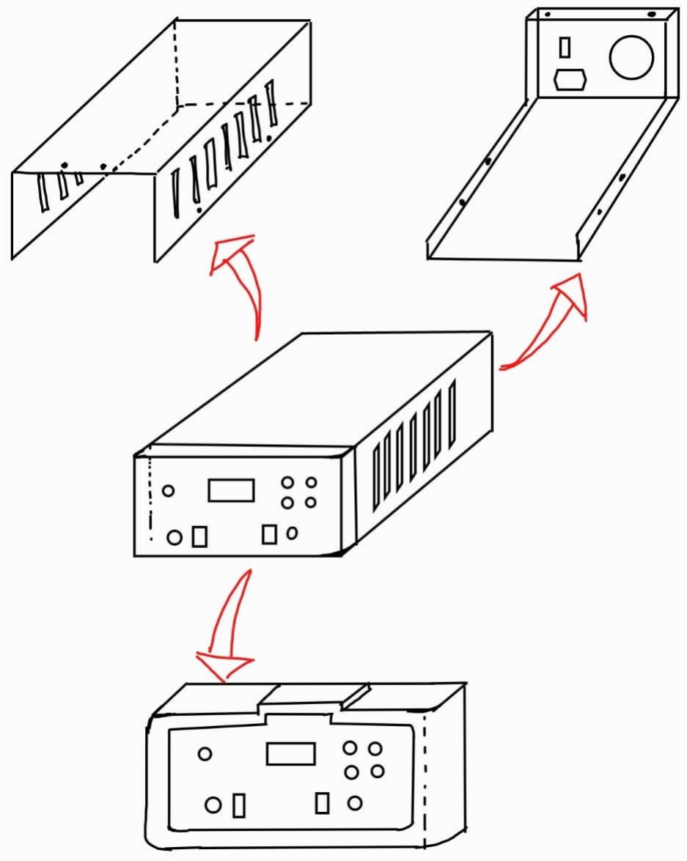
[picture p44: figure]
Figure 3
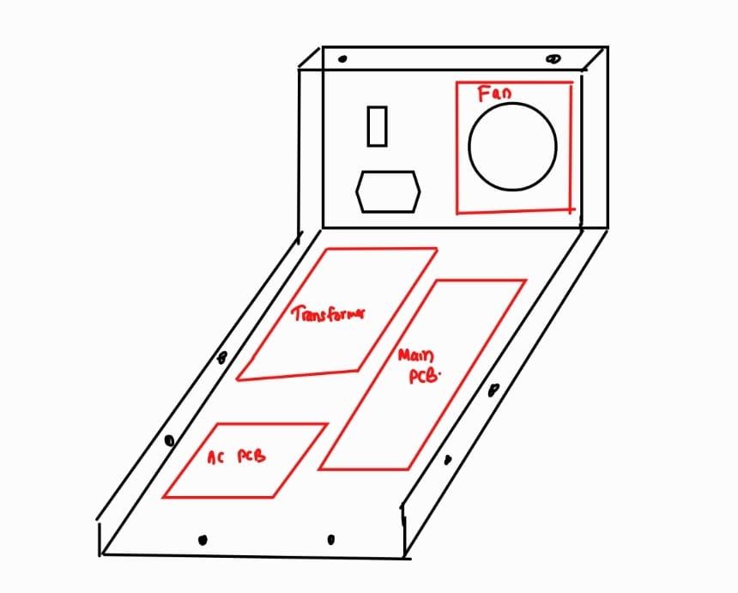
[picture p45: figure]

### 6.2. Wiring Diagram for the system

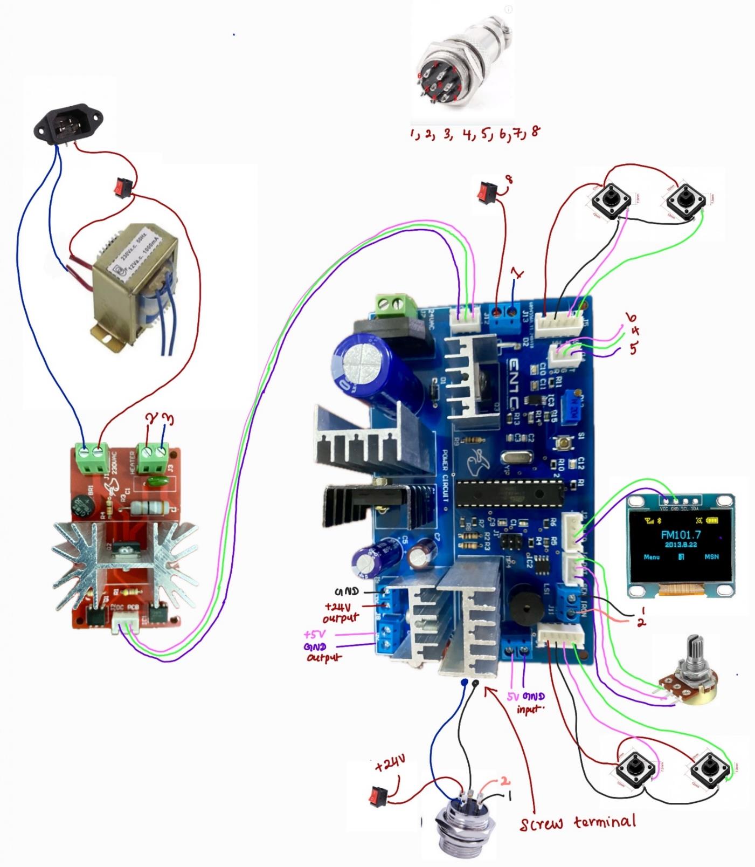
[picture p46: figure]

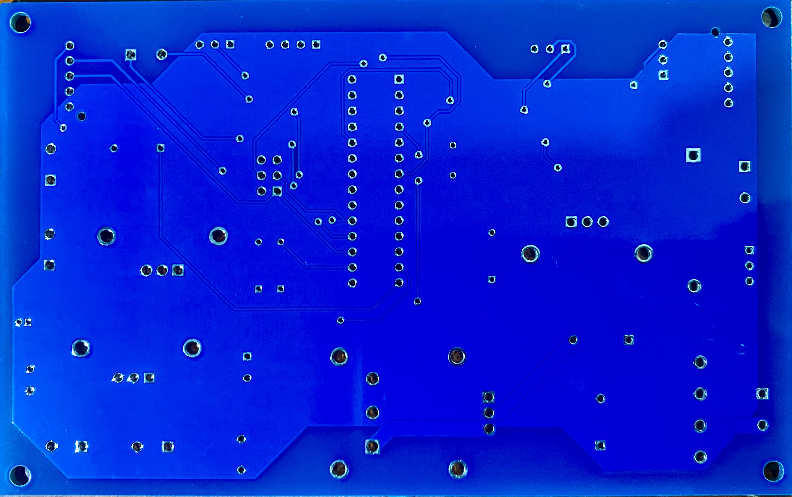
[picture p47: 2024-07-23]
images/printed pcb-dc2 .jpg

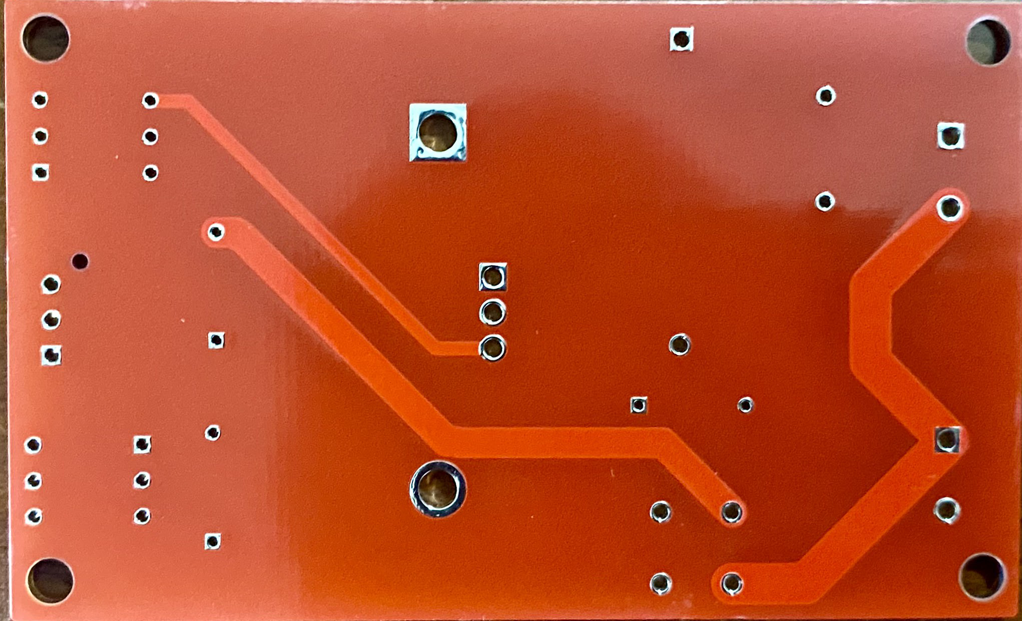
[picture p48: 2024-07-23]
images/printed pcb-dcw .jpg

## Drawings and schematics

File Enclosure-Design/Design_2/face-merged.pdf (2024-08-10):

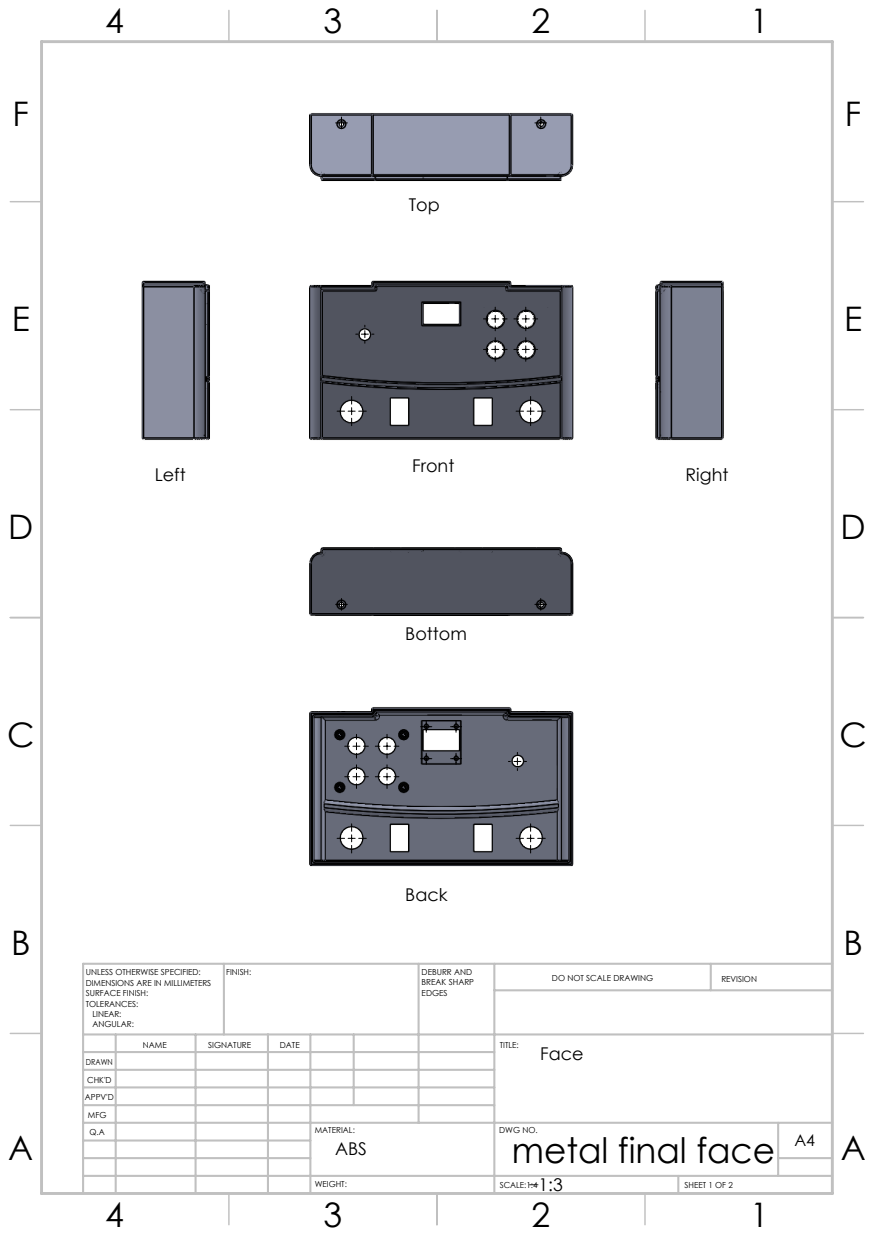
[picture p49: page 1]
FINISH:; DEBURR AND; BREAK SHARP; DO NOT SCALE DRAWING; REVISION; SCALE:1:4; SHEET 1 OF 2

UNLESS OTHERWISE SPECIFIED:
DIMENSIONS ARE IN MILLIMETERS
SURFACE FINISH:
TOLERANCES:
LINEAR:
ANGULAR:

NAME | SIGNATURE | DATE | | | | TITLE: Face

DRAWN
CHK'D
APPV'D
MFG
Q.A | | | | MATERIAL: ABS | DWG NO. metal final face | A4

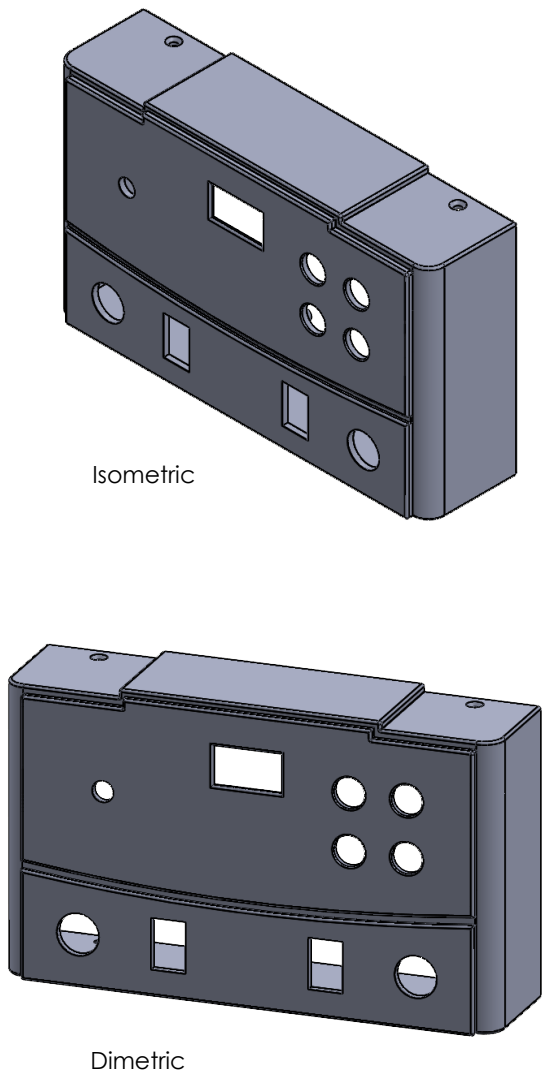
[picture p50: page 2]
FINISH:; DEBURR AND; BREAK SHARP; DO NOT SCALE DRAWING; REVISION

UNLESS OTHERWISE SPECIFIED:
DIMENSIONS ARE IN MILLIMETERS
SURFACE FINISH:
TOLERANCES:
LINEAR:
ANGULAR:

NAME | SIGNATURE | DATE | | | TITLE: Face

DRAWN
CHK'D
APPV'D
MFG

ABS | metal final face

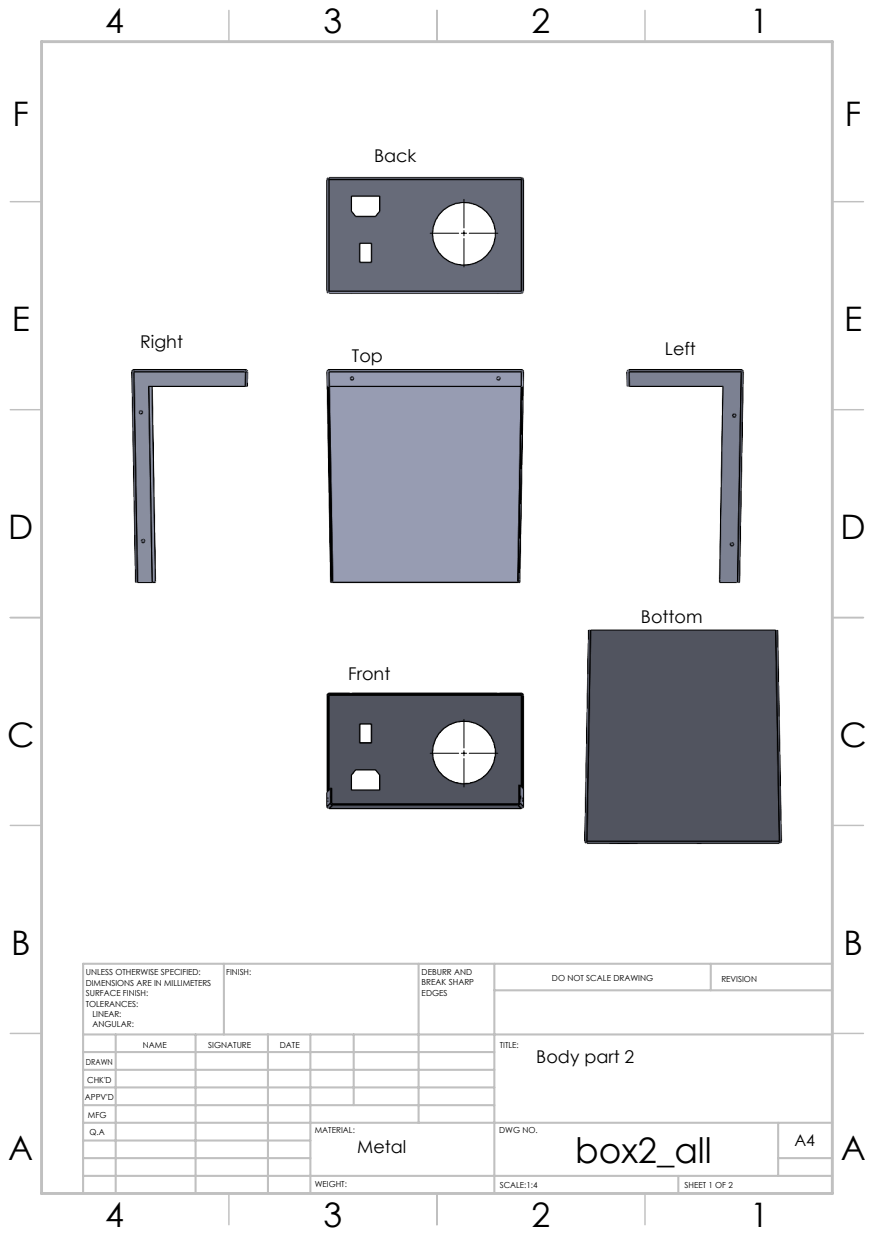
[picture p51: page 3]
FINISH:; DEBURR AND; BREAK SHARP; DO NOT SCALE DRAWING; REVISION

UNLESS OTHERWISE SPECIFIED:
DIMENSIONS ARE IN MILLIMETERS
SURFACE FINISH:
TOLERANCES:
LINEAR:
ANGULAR:

NAME | SIGNATURE | DATE | | TITLE: Body part 2

DRAWN
CHK'D
APPV'D
MFG

box2_all

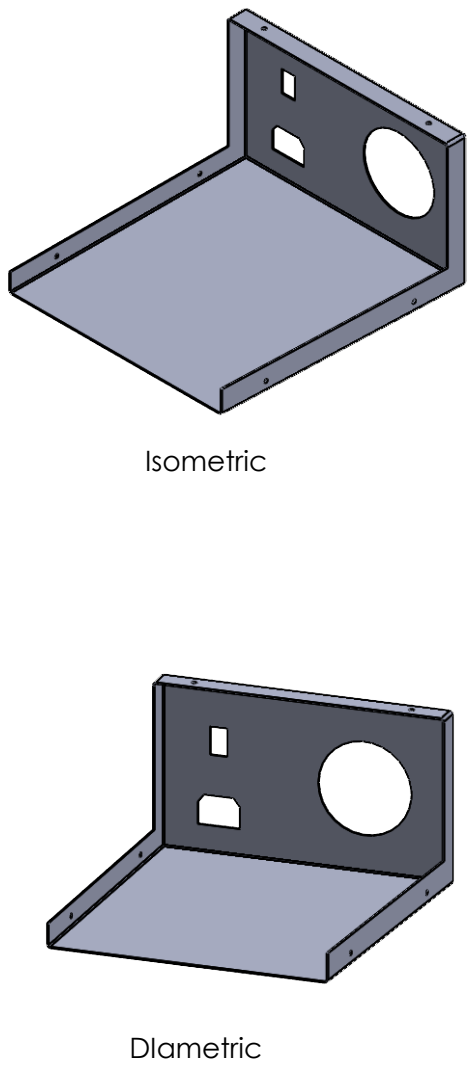
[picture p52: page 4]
FINISH:; DEBURR AND; BREAK SHARP; DO NOT SCALE DRAWING; REVISION

UNLESS OTHERWISE SPECIFIED:
DIMENSIONS ARE IN MILLIMETERS
SURFACE FINISH:
TOLERANCES:
LINEAR:
ANGULAR:

NAME | SIGNATURE | DATE | | TITLE: Body part 2

DRAWN
CHK'D
APPV'D
MFG

box2_all

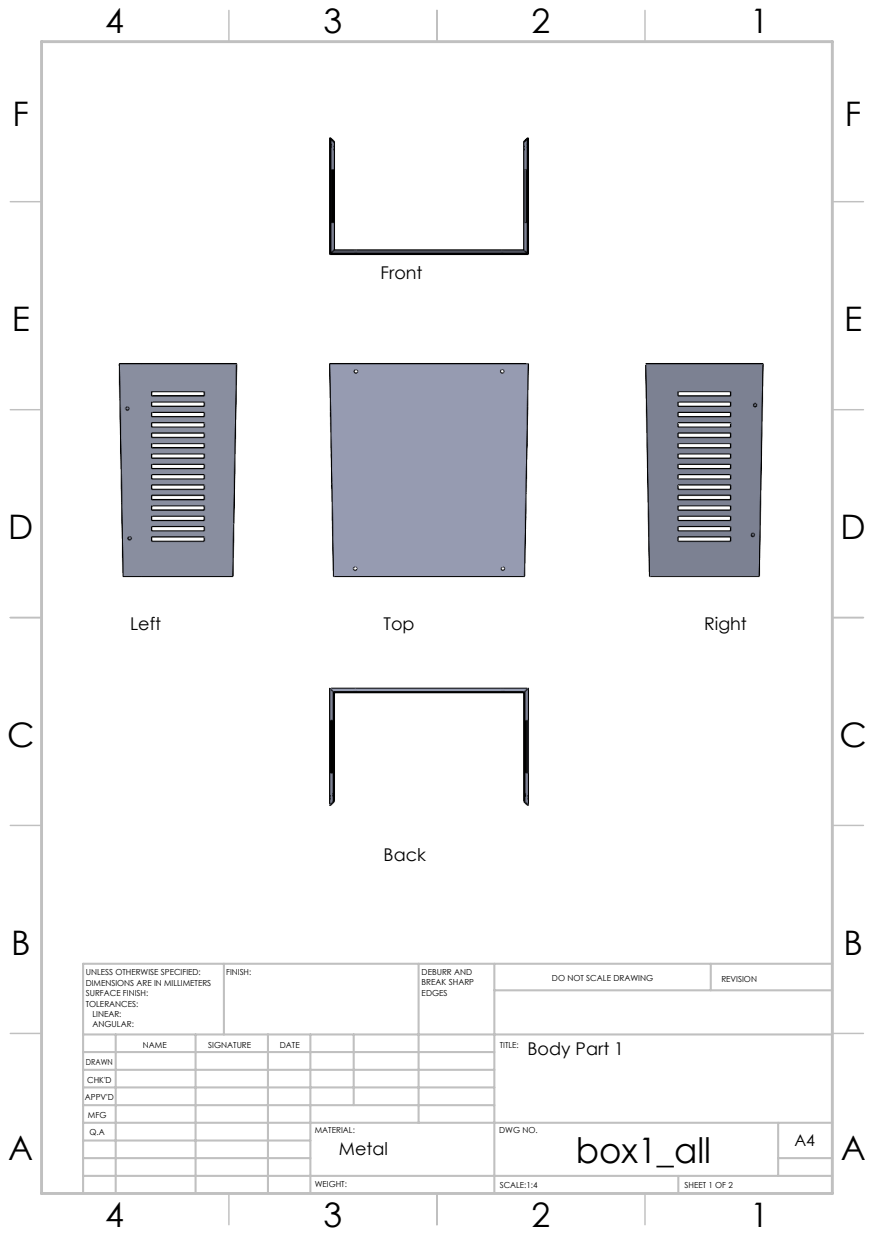
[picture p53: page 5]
FINISH:; DEBURR AND; BREAK SHARP; DO NOT SCALE DRAWING; REVISION

UNLESS OTHERWISE SPECIFIED:
DIMENSIONS ARE IN MILLIMETERS
SURFACE FINISH:
TOLERANCES:
LINEAR:
ANGULAR:

NAME | SIGNATURE | DATE | | TITLE: Body Part 1

DRAWN
CHK'D
APPV'D
MFG

box1_all

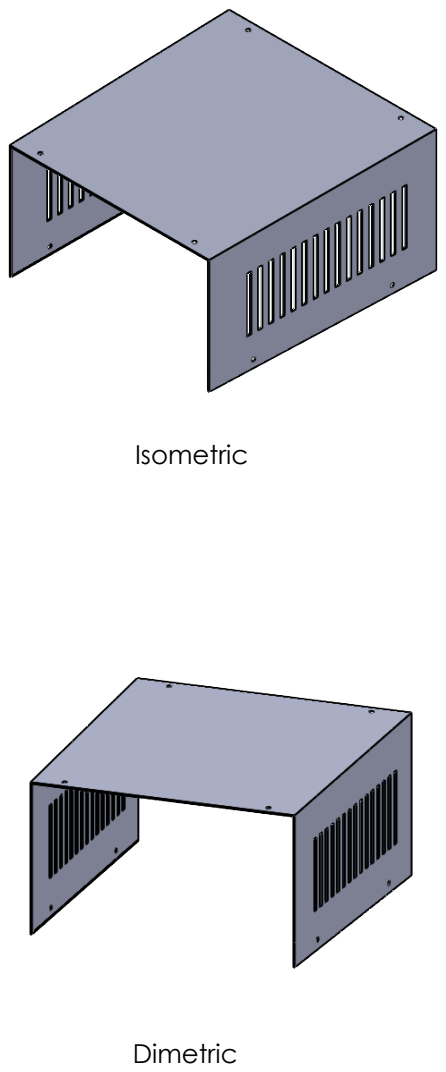
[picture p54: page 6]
FINISH:; DEBURR AND; BREAK SHARP; DO NOT SCALE DRAWING; REVISION

UNLESS OTHERWISE SPECIFIED:
DIMENSIONS ARE IN MILLIMETERS
SURFACE FINISH:
TOLERANCES:
LINEAR:
ANGULAR:

NAME | SIGNATURE | DATE | | TITLE: Body part 1

DRAWN
CHK'D
APPV'D
MFG

box1_all

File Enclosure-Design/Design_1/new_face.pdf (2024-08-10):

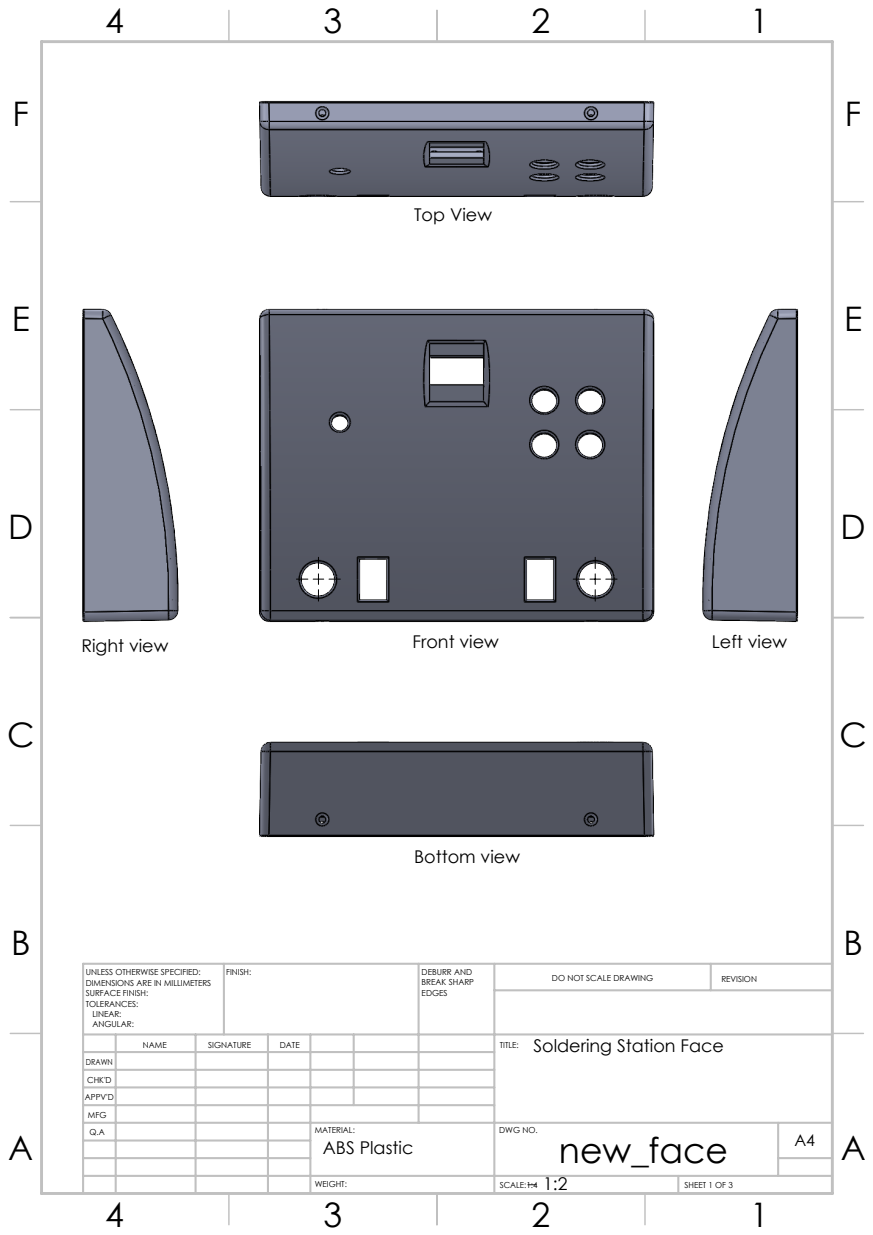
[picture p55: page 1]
Front view; Bottom view; Right view; Left view; Top View; FINISH:; DEBURR AND; BREAK SHARP; DO NOT SCALE DRAWING; REVISION; SCALE:1:4; SHEET 1 OF 3

UNLESS OTHERWISE SPECIFIED:
DIMENSIONS ARE IN MILLIMETERS
SURFACE FINISH:
TOLERANCES:
LINEAR:
ANGULAR:

NAME | SIGNATURE | DATE | | | | Soldering Station Face TITLE:

DRAWN
CHK'D
APPV'D
MFG
Q.A | | | | MATERIAL: ABS Plastic | DWG NO. new_face | A4

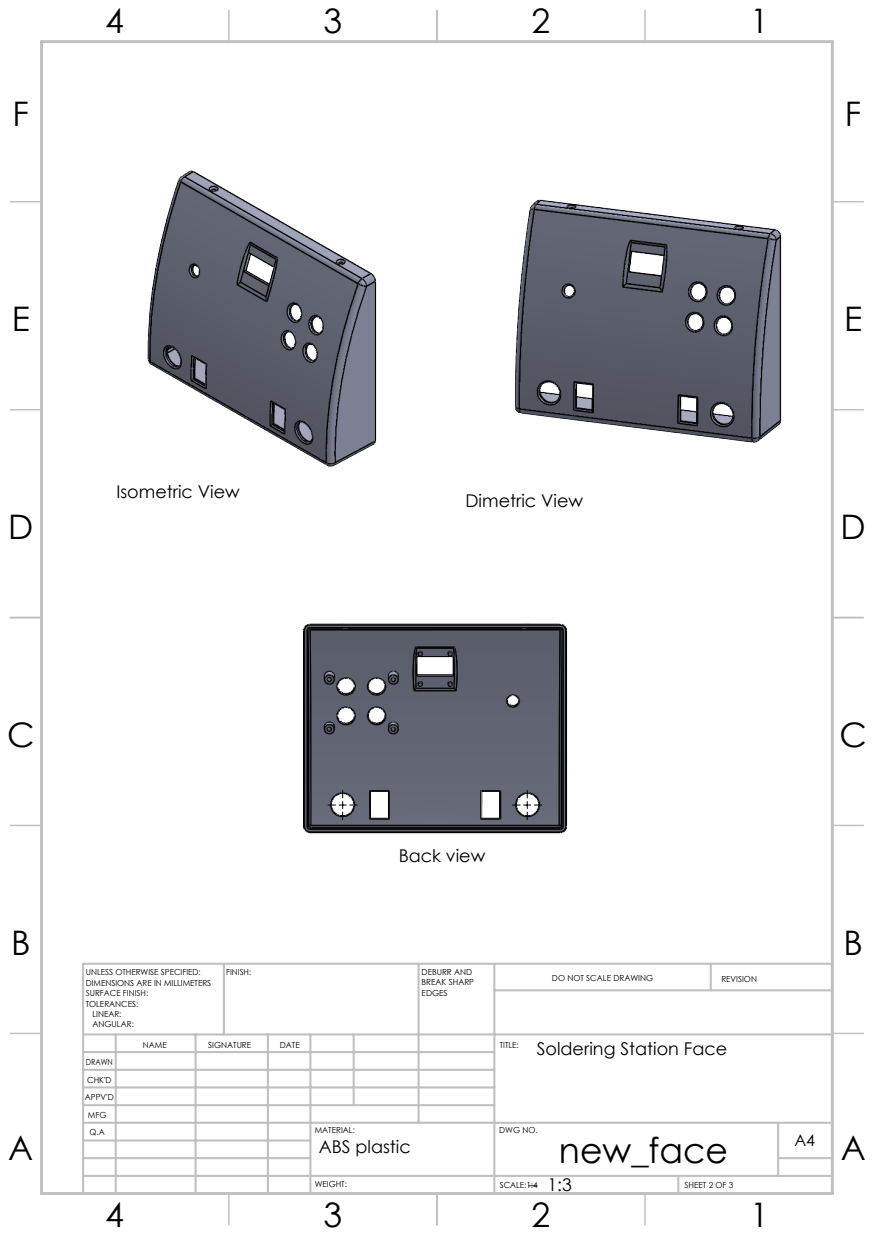
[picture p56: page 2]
Isometric View; Dimetric View; Back view; FINISH:; DEBURR AND; BREAK SHARP; DO NOT SCALE DRAWING; REVISION

UNLESS OTHERWISE SPECIFIED:
DIMENSIONS ARE IN MILLIMETERS
SURFACE FINISH:
TOLERANCES:
LINEAR:
ANGULAR:

NAME | SIGNATURE | DATE | | TITLE: Soldering Station Face

DRAWN
CHK'D
APPV'D
MFG

ABS plastic

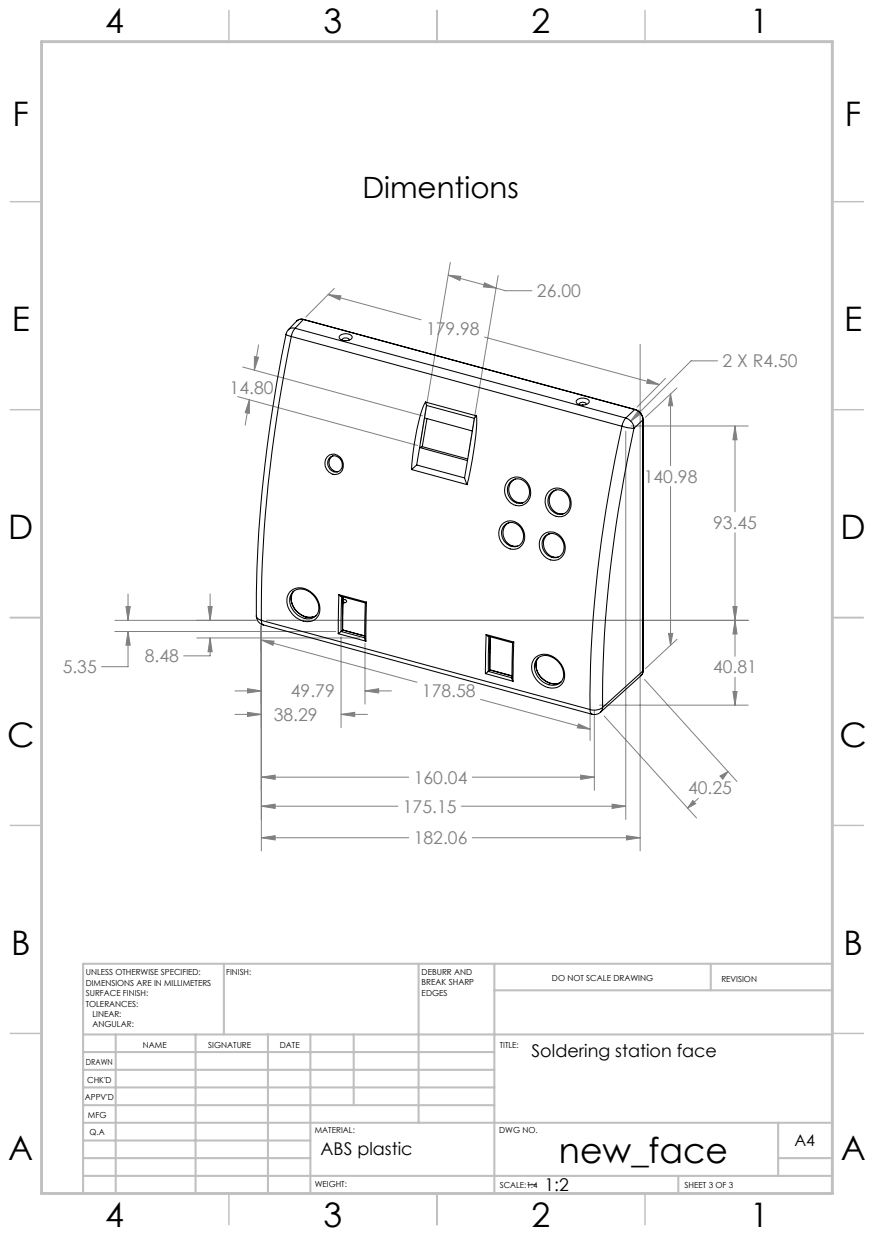
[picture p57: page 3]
FINISH:; DEBURR AND; BREAK SHARP; DO NOT SCALE DRAWING; REVISION

UNLESS OTHERWISE SPECIFIED:
DIMENSIONS ARE IN MILLIMETERS
SURFACE FINISH:
TOLERANCES:
LINEAR:
ANGULAR:

NAME | SIGNATURE | DATE | | TITLE: Soldering station face

DRAWN
CHK'D
APPV'D
MFG

ABS plastic

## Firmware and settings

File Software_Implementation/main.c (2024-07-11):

/**
 * -------------------------------------------------------------------------------------+
 * @desc        LCD FONT 5x8
 * -------------------------------------------------------------------------------------+
 * @source      
 *              Copyright (C) 2020 Marian Hrinko.
 *              Written by Marian Hrinko (mato.hrinko@gmail.com)
 *
 * @author      Marian Hrinko
 * @date        08.12.2020
 * @update      08.12.2022
 * @file        font.h
 * @version     1.0
 * @tested      AVR Atmega328p
 *
 * @depend      
 * -------------------------------------------------------------------------------------+
 * @descr       LCD pixel fonts
 * -------------------------------------------------------------------------------------+
 * @usage       Display characters
 * -------------------------------------------------------------------------------------+
 * 
 * Modified by Rebecca Fernando
 * Date: 2024/07/4
 * Description: Edited for specific project requirements
 */

/**
 * -------------------------------------------------------------------------------------+
 * @brief       SSD1306 OLED Driver
 * -------------------------------------------------------------------------------------+
 *              Copyright (C) 2020 Marian Hrinko.
 *              Written by Marian Hrinko (mato.hrinko@gmail.com)
 *
 * @author      Marian Hrinko
 * @date        06.10.2020
 * @file        ssd1306.h
 * @version     2.0.0
 * @test        AVR Atmega328p
 *
 * @depend      string.h, font.h, twi.h
 * -------------------------------------------------------------------------------------+
 * @brief       Version 1.0 -> applicable for 1 display
 *              Version 2.0 -> rebuild to 'cacheMemLcd' array
 *              Version 3.0 -> simplified alphanumeric version for 1 display
 * -------------------------------------------------------------------------------------+
 * @usage       Basic Setup for OLED Display
 * -------------------------------------------------------------------------------------+
 * 
 * Modified by Rebecca Fernando
 * Date: 2024/07/4

/**
 * -------------------------------------------------------------------------------------+
 * @brief       I2C Library
 * -------------------------------------------------------------------------------------+
 *              Copyright (C) 2017 Michael Köhler
 *
 * @author      Michael Köhler
 * @date        09.10.2017
 * @file        i2c.c
 * -------------------------------------------------------------------------------------+
 * 
 * Modified by Rebecca Fernando
 * Date: 2024/07/4
 
/****************************************************************
 * Arduino PID Library - Version 1.2.1
 * by Brett Beauregard <br3ttb@gmail.com> brettbeauregard.com
 *
 * This Library is licensed under the MIT License
 ****************************************************************
 * 
 * For an ultra-detailed explanation of why the code is the way it is, please visit: 
 * http://brettbeauregard.com/blog/2011/04/improving-the-beginners-pid-introduction/
 * 
 * For function documentation see: 
 * http://playground.arduino.cc/Code/PIDLibrary
 * (Click "Libraries" on the left panel. The link to the documentation is listed as "PIDLibrary - Provides basic feedback control".)
 ****************************************************************
 * 
 * Modified by Rebecca Fernando
 * Date: 2024/07/4
 *Description: Edited for specific project Solering Station
*/

#include <avr/io.h>
#include <avr/interrupt.h>
#include <avr/eeprom.h>
#include <stdbool.h>
#include <string.h>
#include <stdlib.h>
#include <stdio.h>
#include <util/atomic.h>
#define F_CPU 16000000UL
#include <util/delay.h>

#define SCREEN_WIDTH 128
#define SCREEN_HEIGHT 64
#define SCREEN_ADDRESS 0x3C

// Pin definitions
#define PB_BACK    PB0   // Pin 8 on Arduino, mapped to Port B, Pin 0 (PB0)
#define PB_OK      PD7   // Pin 7 on Arduino, mapped to Port D, Pin 7 (PD7)
#define PB_UP      PD4   // Pin 4 on Arduino, mapped to Port D, Pin 4 (PD4)
#define PB_DOWN    PD2   // Pin 2 on Arduino, mapped to Port D, Pin 2 (PD2)

#define CONTROL_PIN_IRON    PB2   // Pin 16 on Arduino, mapped to Port B, Pin 2 (PB2)
#define CONTROL_PIN_GUN     PB3   // Pin 17 on Arduino, mapped to Port B, Pin 3 (PB3)

#define TEMP_PIN_IRON       PC1   // Pin A1 on Arduino, mapped to Port C, Pin 1 (PC1)
#define TEMP_PIN_GUN        PC2   // Pin A2 on Arduino, mapped to Port C, Pin 2 (PC2)

// Global variables
bool in_temp_display = false;
bool in_menu1 = false;
bool in_choice = false;

const char* gun_iron[2] = {"Both", "Hot air gun"};
int selected = 0;
const char* menu1[2] = {"Sleep Mode", "Tip Change"};
int select_m1 = 0;

int Setpoint_iron = 150;
int Setpoint_gun = 150;

bool sleeping = false;
volatile unsigned long last_activity_time = 0;
unsigned long sleep_duration = 60000; // 1 minute for testing

double aggKp = 4, aggKi = 0.2, aggKd = 1;
double consKp = 1, consKi = 0.05, consKd = 0.25;
double outMin, outMax;

double Input_iron;
double Output_iron;
double Setpoint;
double Input_gun;
double Output_gun;

void I2C_Init();
void I2C_Start();
void I2C_Write(uint8_t data);
void SCREEN_Command(uint8_t command);
void SCREEN_Data(uint8_t data);
void SCREEN_Init();
void SCREEN_Clear();
void SCREEN_SetCursor(uint8_t row, uint8_t col);
void SCREEN_WriteChar(uint8_t ch, uint8_t size);
void SCREEN_Printf(const char *str, uint8_t size);
void go_to_menu();
void display_temp(int setpoint);
void go_to_menu1();
void run_mode(int mode);
double readTemperature(int pin);
void checkSleepMode();
void wakeUp();
void sleepMode();
void tipChange();
void display_A_Menu(int arrowIndex, const char* Arr[], int Arr_len, int textSize);
int wait_for_button_press();
void millis_init();
unsigned long millis();


void millis_init() {
	// Configure Timer0 for 1ms interrupt using prescaler 64
	TCCR0A = 0x00;             // Normal mode
	TCCR0B = (1 << CS01) | (1 << CS00); // Prescaler 64
	TIMSK0 = (1 << TOIE0);     // Enable overflow interrupt for Timer0
	TCNT0 = 0;                 // Initialize counter
}

// Interrupt Service Routine for Timer0 Overflow
ISR(TIMER0_OVF_vect) {
	last_activity_time++; // Increment millis_count in the ISR
}

unsigned long millis()
{
	unsigned long millis_value;
	// Ensure atomic access to millis_count
	ATOMIC_BLOCK(ATOMIC_FORCEON) {
		millis_value = last_activity_time;
	}
	return millis_value;
}

// Font array for ASCII characters
const uint8_t font[][8] = {
	{0x00, 0x00, 0x00, 0x00, 0x00, 0x00, 0x00, 0x00},  // Space (32)
	{0x00, 0x00, 0x00, 0x00, 0x00, 0x00, 0x00, 0x00},  // ! (33)
	{0x00, 0x00, 0x07, 0x00, 0x00, 0x07, 0x00, 0x00},  // ' (39)
	{0x00, 0x1C, 0x1C, 0x00, 0x1C, 0x1C, 0x00, 0x00},  // ( (40)
	{0x00, 0x1C, 0x1C, 0x00, 0x1C, 0x1C, 0x00, 0x00},  // ) (41)
	{0x00, 0x00, 0x00, 0x00, 0x1C, 0x00, 0x00, 0x00},  // , (44)
	{0x00, 0x00, 0x00, 0x1C, 0x1C, 0x00, 0x00, 0x00},  // - (45)
	{0x00, 0x00, 0x00, 0x00, 0x1C, 0x00, 0x00, 0x00},  // . (46)
	{0x00, 0x00, 0x00, 0x1C, 0x1C, 0x1C, 0x00, 0x00},  // / (47)
	{0x00, 0x1C, 0x1C, 0x1C, 0x1C, 0x1C, 0x00, 0x00},  // 0 (48)
	{0x00, 0x07, 0x07, 0x00, 0x07, 0x07, 0x00, 0x00},  // 1 (49)
	{0x00, 0x1C, 0x07, 0x1C, 0x1C, 0x1C, 0x00, 0x00},  // 2 (50)
	{0x00, 0x1C, 0x07, 0x00, 0x07, 0x1C, 0x00, 0x00},  // 3 (51)
	{0x00, 0x07, 0x07, 0x1C, 0x07, 0x07, 0x00, 0x00},  // 4 (52)
	{0x00, 0x1C, 0x1C, 0x00, 0x1C, 0x07, 0x00, 0x00},  // 5 (53)
	{0x00, 0x1C, 0x1C, 0x1C, 0x1C, 0x1C, 0x00, 0x00},  // 6 (54)
	{0x00, 0x07, 0x07, 0x00, 0x07, 0x07, 0x00, 0x00},  // 7 (55)
	{0x00, 0x1C, 0x1C, 0x1C, 0x1C, 0x1C, 0x00, 0x00},  // 8 (56)
	{0x00, 0x1C, 0x1C, 0x00, 0x1C, 0x1C, 0x00, 0x00},  // 9 (57)
	{0x00, 0x00, 0x1C, 0x1C, 0x1C, 0x00, 0x00, 0x00},  // : (58)
	{0x00, 0x00, 0x00, 0x1C, 0x1C, 0x00, 0x00, 0x00},  // ; (59)
	{0x00, 0x00, 0x07, 0x1C, 0x07, 0x00, 0x00, 0x00},  // < (60)
	{0x00, 0x00, 0x1C, 0x1C, 0x1C, 0x1C, 0x00, 0x00},  // = (61)
	{0x00, 0x00, 0x07, 0x1C, 0x07, 0x00, 0x00, 0x00},  // > (62)
	{0x00, 0x00, 0x1C, 0x07, 0x1C, 0x00, 0x00, 0x00},  //? (63)
	{0x00, 0x07, 0x07, 0x1C, 0x07, 0x07, 0x00, 0x00},  // A (65)
	{0x00, 0x1C, 0x1C, 0x1C, 0x1C, 0x1C, 0x00, 0x00},  // B (66)
	{0x00, 0x1C, 0x07, 0x07, 0x07, 0x1C, 0x00, 0x00},  // C (67)
	{0x00, 0x1C, 0x1C, 0x1C, 0x1C, 0x1C, 0x00, 0x00},  // D (68)
	{0x00, 0x1C, 0x1C, 0x00, 0x1C, 0x1C, 0x00, 0x00},  // E (69)
	{0x00, 0x1C, 0x1C, 0x00, 0x1C, 0x1C, 0x00, 0x00},  // F (70)
	{0x00, 0x1C, 0x1C, 0x1C, 0x1C, 0x1C, 0x00, 0x00},  // G (71)
	{0x00, 0x07, 0x07, 0x1C, 0x07, 0x07, 0x00, 0x00},  // H (72)
	{0x00, 0x1C, 0x00, 0x1C, 0x00, 0x1C, 0x00, 0x00},  // I (73)
	{0x00, 0x1C, 0x07, 0x07, 0x07, 0x07, 0x00, 0x00},  // J (74)
	{0x00, 0x07, 0x1C, 0x1C, 0x1C, 0x07, 0x00, 0x00},  // K (75)
	{0x00, 0x00, 0x1C, 0x1C, 0x1C, 0x1C, 0x00, 0x00},  // L (76)
	{0x00, 0x07, 0x1C, 0x1C, 0x07, 0x07, 0x00, 0x00},  // M (77)
	{0x00, 0x1C, 0x1C, 0x1C, 0x1C, 0x1C, 0x00, 0x00},  // N (78)
	{0x00, 0x1C, 0x07, 0x07, 0x07, 0x1C, 0x00, 0x00},  // O (79)
	{0x00, 0x07, 0x07, 0x1C, 0x1C, 0x1C, 0x00, 0x00},  // P (80)
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
};

void I2C_Init() {
	// Initialize I2C with 100 kHz baud rate
	TWBR = 72;  // Calculated value for 100 kHz at 16 MHz CPU clock
	TWSR &= ~(1<<TWPS0) & ~(1<<TWPS1);  // Prescaler = 1
}

void I2C_Start() {
	TWCR = (1<<TWINT) | (1<<TWSTA) | (1<<TWEN);  // Start condition
	while (!(TWCR & (1<<TWINT)));  // Wait for start condition to be transmitted
}

void I2C_Write(uint8_t data) {
	TWDR = data;
	TWCR = (1<<TWINT) | (1<<TWEN);  // Clear TWINT to start transmission of data
	while (!(TWCR & (1<<TWINT)));  // Wait for transmission to complete
}

void SCREEN_Command(uint8_t command) {
	I2C_Start();
	I2C_Write(SCREEN_ADDRESS << 1);  // Slave address + write mode
	I2C_Write(0x00);            // Command mode
	I2C_Write(command);
	TWCR = (1<<TWINT) | (1<<TWEN) | (1<<TWSTO);  // Stop condition
	_delay_us(10);  // Small delay
}

void SCREEN_Data(uint8_t data) {
	I2C_Start();
	I2C_Write(SCREEN_ADDRESS << 1);  // Slave address + write mode
	I2C_Write(0x40);            // Data mode
	I2C_Write(data);
	TWCR = (1<<TWINT) | (1<<TWEN) | (1<<TWSTO);  // Stop condition
	_delay_us(10);  // Small delay
}

void SCREEN_Init() {
	I2C_Init();  // Initialize I2C communication
	_delay_ms(100);  // Delay for stable power-on
	SCREEN_Command(0xAE);  // Display off
	SCREEN_Command(0x20);  // Set Memory Addressing Mode
	SCREEN_Command(0x10);  // 00,Horizontal Addressing Mode;01,Vertical Addressing Mode;
	// 10,Page Addressing Mode (RESET);11,Invalid
	SCREEN_Command(0xB0);  // Set Page Start Address for Page Addressing Mode,0-7
	SCREEN_Command(0xC8);  // Set COM Output Scan Direction
	SCREEN_Command(0x00);  // ---set low column address
	SCREEN_Command(0x10);  // ---set high column address
	SCREEN_Command(0x40);  // --set start line address
	SCREEN_Command(0x81);  // Set contrast control register
	SCREEN_Command(0xFF);  // --set segment re-map 0 to 127
	SCREEN_Command(0xA1);  // Set Display RAM Horizontal Flip (0xA0,0xA1)
	SCREEN_Command(0xA6);  // Set display mode (0xA6,0xA7)
	SCREEN_Command(0xA8);  // Set Multiplex Ratio (1 to 64)
	SCREEN_Command(0x3F);  // 1/64 duty
	SCREEN_Command(0xA4);  // Output follows RAM content;0xa4;Output ignores RAM content
	SCREEN_Command(0xD3);  //-set display offset
	SCREEN_Command(0x00);   //-not offset
	SCREEN_Command(0xD5);  //--set display clock divide ratio/oscillator frequency
	SCREEN_Command(0xF0);  //--set divide ratio, Set Clock as 100 Frames/Sec
	SCREEN_Command(0xD9);  //--set pre-charge period
	SCREEN_Command(0x22);   //
	SCREEN_Command(0xDA);  //--set com pins hardware configuration
	SCREEN_Command(0x12);
	SCREEN_Command(0xDB);  //--set vcomh
	SCREEN_Command(0x20);  //0x20,0.77xVcc
	SCREEN_Command(0x8D);  //--set DC-DC enable
	SCREEN_Command(0x14);
	SCREEN_Command(0xAF);  //--turn on SCREEN panel
	SCREEN_Command(0xAF);
	SCREEN_Command(0xB1);  // Set Phase Length
	SCREEN_Command(0x1D);  // Select External Vcc Supply

	SCREEN_Command(0xB3);  // Set Display Clock Divide Ratio/Oscillator Frequency
	SCREEN_Command(0xF1);  // Set Display Divide Ratio 3e, 3f
}

void SCREEN_Clear() {
	uint8_t i, j;
	for (j = 0; j < 8; j++) {
		SCREEN_Command(0xB0 + j);  // Set page address (0 to 7)
		SCREEN_Command(0x00);      // Set low column address
		SCREEN_Command(0x10);      // Set high column address
		for (i = 0; i < 128; i++) {
			SCREEN_Data(0x00);     // Clear entire page
		}
	}
}

void SCREEN_SetCursor(uint8_t row, uint8_t col) {
	SCREEN_Command(0xB0 + row);            // Set page address
	SCREEN_Command(0x00 + (8*col & 0x0F)); // Set column lower address
	SCREEN_Command(0x10 + ((8*col>>4)&0x0F));// Set column higher address
}

void SCREEN_WriteChar(uint8_t ch, uint8_t size) {
	uint8_t i, j;
	for (i = 0; i < 8; i++) {
		for (j = 0; j < size; j++) {
			SCREEN_Data(font[ch - 32][i]);  // Print each row of the character
		}
	}
}

void SCREEN_Printf(const char *str, uint8_t size) {
	while (*str) {
		SCREEN_WriteChar(*str++, size);
	}
}

// PID control class 
typedef struct {
	double *myInput;    // pointer to input value
	double *myOutput;   // pointer to output value
	double *mySetpoint; // pointer to setpoint value
	
	double kp;          // proportional gain
	double ki;          // integral gain
	double kd;          // derivative gain
	
	bool inAuto;        // flag indicating whether the controller is in automatic mode
	unsigned long SampleTime; // sample time in milliseconds
	unsigned long lastTime;   // last time the controller was updated
	
	double outputSum;   // sum of errors for integral term
	double lastInput;   // last input for derivative term
	
	double outMin;      // minimum output limit
	double outMax;      // maximum output limit
} PID;

void PID_Init(PID *pid, double *input, double *output, double *setpoint, double Kp, double Ki, double Kd, int direction) {
	pid->myInput = input;
	pid->myOutput = output;
	pid->mySetpoint = setpoint;
	pid->kp = Kp;
	pid->ki = Ki;
	pid->kd = Kd;
	pid->inAuto = true;
	pid->SampleTime = 100;
	pid->lastTime = millis() - pid->SampleTime;
	pid->outputSum = 0;
	pid->lastInput = 0;
}

void PID_Compute(PID *pid) {
	if (!pid->inAuto) return;
	
	unsigned long now = millis();
	unsigned long timeChange = (now - pid->lastTime);
	if (timeChange >= pid->SampleTime) {
		double input = *(pid->myInput);
		double error = *(pid->mySetpoint) - input;
		pid->outputSum += (pid->ki * error);
		
		double output = pid->kp * error + pid->outputSum - pid->kd * (input - pid->lastInput);
		*(pid->myOutput) = output;
		
		if (*(pid->myOutput) > pid->outMax) *(pid->myOutput) = pid->outMax;
		else if (*(pid->myOutput) < pid->outMin) *(pid->myOutput) = pid->outMin;
		
		pid->lastInput = input;
		pid->lastTime = now;
	}
}

void PID_SetTunings(PID *pid,double Kp,double Ki,double Kd) {
	pid->kp = Kp;
	pid->ki = Ki;
	pid->kd = Kd;
}

void PID_SetOutputLimits(PID *pid,double Min,double Max) {
	if (Min >= Max) return;
	pid->outMin = Min;
	pid->outMax = Max;
	
	if (*(pid->myOutput) > pid->outMax) *(pid->myOutput) = pid->outMax;
	else if (*(pid->myOutput) < pid->outMin) *(pid->myOutput) = pid->outMin;
	
	if (pid->outputSum > pid->outMax) pid->outputSum = pid->outMax;
	else if (pid->outputSum < pid->outMin) pid->outputSum = pid->outMin;
}

void PID_SetMode(PID *pid, int Mode) {
	pid->inAuto = (Mode == 1);
}

PID myPIDIron, myPIDGun;
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
int main()
{
	setup();
	while (1)
	{
		loop();
	}
}

void display_A_Menu(int arrowIndex, const char* Arr[], int Arr_len, int textSize) {
	SCREEN_Clear();
	for (int i = 0; i < Arr_len; i++) {
		SCREEN_SetCursor(i, 0);
		if (i == arrowIndex) {
			SCREEN_Printf("> ",1);
			} else {
			SCREEN_Printf("  ",1);
		}
		SCREEN_Printf(Arr[i],1);
	}
}

int wait_for_button_press()
{
	while (1) {
		if (!(PIND & (1 << PB_UP))) {
			_delay_ms(200);
			return PB_UP;
		}
		if (!(PIND & (1 << PB_DOWN))) {
			_delay_ms(200);
			return PB_DOWN;
		}
		if (!(PIND & (1 << PB_OK))) {
			_delay_ms(200);
			return PB_OK;
		}
		if (!(PIND & (1 << PB_BACK))) {
			_delay_ms(200);
			return PB_BACK;
		}
	}
}

void go_to_menu()
{
	while (PIND & (1 << PB_BACK)) {
		SCREEN_Clear();
		display_A_Menu(selected, gun_iron, 2, 1);
		int pressed = wait_for_button_press();
		if (pressed == PB_UP) {
			_delay_ms(200);
			selected = (selected + 1) % 2;
			display_A_Menu(selected, gun_iron, 2, 1);
			} else if (pressed == PB_DOWN) {
			_delay_ms(200);
			selected = (selected - 1 + 2) % 2;
			display_A_Menu(selected, gun_iron, 2, 1);
			} else if (pressed == PB_OK) {
			_delay_ms(200);
			in_choice = false;
			in_temp_display = true;
			last_activity_time = millis(); // Update activity time
			break;
			} else if (pressed == PB_BACK) {
			_delay_ms(200);
			// Do something if needed
		}
	}
}

void display_temp(int setpoint) {
	SCREEN_Clear();
	SCREEN_SetCursor(0,20);

	if (selected) {
		SCREEN_Printf( "Set Gun Temp: ",2);
		} else {
		SCREEN_Printf(  "Set Iron Temp: ",2);
	}

	char* temp_str = malloc(12);
	snprintf(temp_str, 12, "%d", setpoint);
	const char* const_temp_str = temp_str;

	SCREEN_Printf(const_temp_str,2);
	SCREEN_WriteChar('c',2);


	int pressed = wait_for_button_press();
	if (pressed == PB_BACK) {
		_delay_ms(200);
		in_choice = true;
		} else if (pressed == PB_UP) {
		_delay_ms(200);
		if (selected) {
			Setpoint_gun += 1;
			if (Setpoint_gun > 400) {
				Setpoint_gun = 400;
			}
			} else {
			setpoint += 1;
			if (setpoint > 400) {
				setpoint = 400;
			}
			eeprom_update_word((uint16_t*)0, setpoint);
		}
		last_activity_time = millis(); // Update activity time
		} else if (pressed == PB_DOWN) {
		_delay_ms(200);
		if (selected) {
			Setpoint_gun -= 1;
			if (Setpoint_gun < 150) {
				Setpoint_gun = 150;
			}
			} else {
			setpoint -= 1;
			if (setpoint < 150) {
				setpoint = 150;
			}
			eeprom_update_word((uint16_t*)0, setpoint);
		}
		last_activity_time = millis(); // Update activity time
		} else if (pressed == PB_OK) {
		_delay_ms(200);
		if (!selected) {
			in_choice = false;
			in_temp_display = false;
			in_menu1 = true;
		}
	}
}

void go_to_menu1() {
	while (PIND & (1 << PB_BACK)) {
		SCREEN_Clear();
		display_A_Menu(select_m1, menu1, 2, 1);
		int pressed = wait_for_button_press();
		if (pressed == PB_UP) {
			_delay_ms(200);
			select_m1 = (select_m1 + 1) % 2;
			display_A_Menu(select_m1, menu1, 2, 1);
			} else if (pressed == PB_DOWN) {
			_delay_ms(200);
			select_m1 = (select_m1 - 1 + 2) % 2;
			display_A_Menu(select_m1, menu1, 2, 1);
			} else if (pressed == PB_OK) {
			_delay_ms(200);
			int mode = select_m1;
			run_mode(mode);
			} else if (pressed == PB_BACK) {
			_delay_ms(200);
			in_choice = false;
			in_menu1 = false;
			in_temp_display = true;
			break;
		}
	}
}

void run_mode(int mode) {
	if (mode == 0) {
		sleepMode();
		} else if (mode == 1) {
		tipChange();
	}
}

void tipChange() {
	SCREEN_Clear();
	SCREEN_SetCursor(0,20);
	SCREEN_Printf("Tip Changed",2);
	_delay_ms(1000);
	// Lower temperature for safe tip change
	int original_setpoint = eeprom_read_word((uint16_t*)0); // Read from EEPROM
	Setpoint_iron = 100; // Example lower temperature
	eeprom_update_word((uint16_t*)0, Setpoint_iron);
	_delay_ms(5000); // Wait for 5 seconds
	Setpoint_iron = original_setpoint;
	eeprom_update_word((uint16_t*)0, Setpoint_iron);
	SCREEN_Clear();
}

void checkSleepMode() {
	if (millis() - last_activity_time > sleep_duration && !sleeping) {
		sleepMode();
		sleeping = true;
	}
}

void wakeUp() {
	SCREEN_Clear();
	SCREEN_SetCursor(0,20);
	SCREEN_Printf("Waking up...",2);
	_delay_ms(1000);
	sleeping = false;
	last_activity_time = millis();
	SCREEN_Clear();
}

void sleepMode() {
	SCREEN_Clear();
	SCREEN_SetCursor(0,20);
	SCREEN_Printf("Sleeping...",2);
	_delay_ms(1000);
	// Enter low power mode or stop heating elements
	OCR0A = 0;  // Stop heating elements of iron
	OCR0B = 0;  // Stop heating elements of gun
	while (1) {
		if (!(PIND & (1 << PB_OK)) || !(PIND & (1 << PB_UP)) || !(PIND & (1 << PB_DOWN)) || !(PIND & (1 << PB_BACK))) {
			wakeUp();
			break;
		}
	}
}

double readTemperature(int pin) {
	// Select ADC channel
	ADMUX = (ADMUX & 0xF0) | (pin & 0x0F);
	// Start conversion
	ADCSRA |= (1 << ADSC);
	// Wait for conversion to complete
	while (ADCSRA & (1 << ADSC));
	double input = ADC;
	input = ((input / 1024.0) * 500.0);  // Assuming a 5V reference
	
	// Map the input value from 0-450 to 25-350
	double mappedInput = (input - 0) * (350.0 - 25.0) / (450.0 - 0) + 25.0;
	return mappedInput;
}

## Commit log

2024-07-11 Create Arduino_code
2024-07-16 Rename printed pcb-dc .jpg to printed-pcb-dc.jpg
2024-07-16 Rename printed pcb-ac .jpg to printed-pcb-ac.jpg
